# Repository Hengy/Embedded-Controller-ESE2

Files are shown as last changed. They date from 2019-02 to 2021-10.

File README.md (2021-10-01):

# Embedded-Controller-ESE2

This repository contains project files for the 2nd year Conestoga ESE project: Embedded Robot Controller PCB.

The PCB is a 4-layer board with connections for a STM32F303 Nucleo development board, LCD display, RS232 port, uSD card slot, RTC backup battery, Stepper motor driver, Dual DC motor driver, CANbus transciever, Bluetooth module, ultrasonic distance sensor, encoder input, and GPIO. GPIO include I2C and SPI connections.

The board runs of 12-14V, and includes a 5V switch mode buck converter, and a 3V3 linear regulator. Voltage input includes reverse polarity protection.

Layer stackup: (1) signal with ground plane (2) 5V power (3) ground (4) signal with ground plane.

PCB features include thermally enhanced features for motor drivers, thermistors for motor drivers to monitor temperature, numerous and easily accessilble test points, mechanical support for LCD display module, GPIO headers compatible with Tektronics MSO digital probes, and 5V and 3V3 isolation for debugging.

Switch mode power supply adheres to SMPS layout best practices, including small loop area.

Majority of components are SMD. PCB is capable of being oven reflowed on both sides - bottom first. Hand soldering is possible.

Project includes full 3D model.

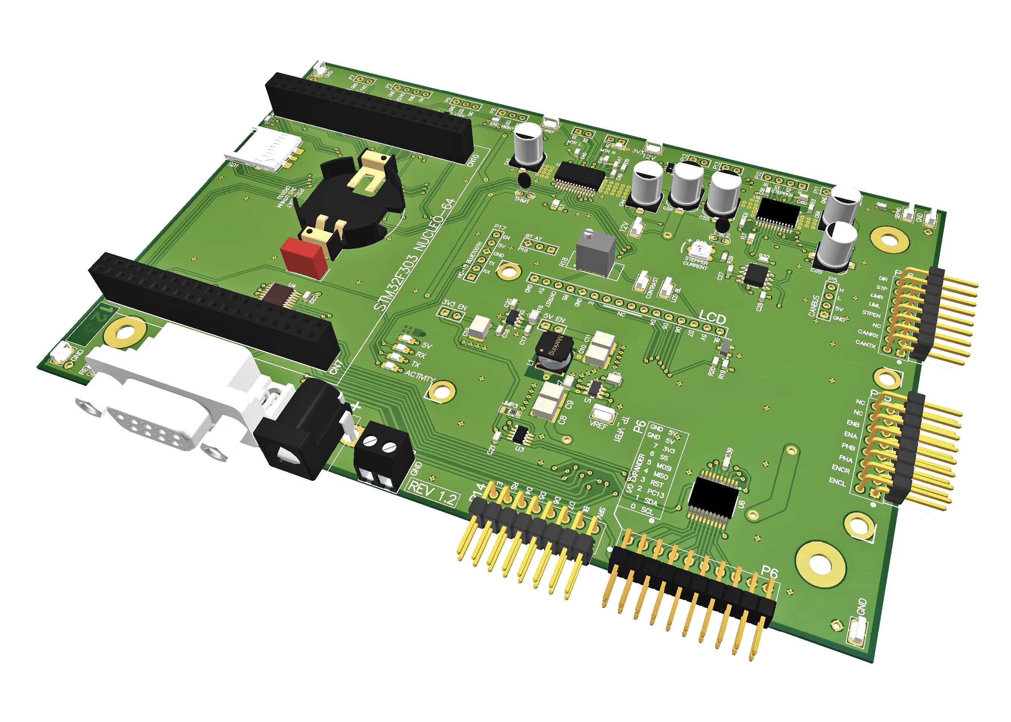
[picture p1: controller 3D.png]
PCB


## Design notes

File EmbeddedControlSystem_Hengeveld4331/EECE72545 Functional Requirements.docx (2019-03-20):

EECE72545

Project Functional Requirements

Matthew Hengeveld

8534331

2/27/2019

Document Title | Hardware Functional Specification
Revision | 1.2
Date Issued | March 4, 2019
Date Effective | March 4, 2019
Program | Electronic Systems Engineering
Author | Matthew Hengeveld
Reviewers | Matthew Hengeveld

REVISION HISTORY

Revision | Description of Change | Effective Date
1.0 | Initial Release | Jan 18, 2019
1.1 | Updated Topics | Feb 15, 2019
1.2 | PCB Layout Completion Update | Mar 8, 2019

TABLE OF CONTENTS

Document Scope | 3
Cost Targets | 3
Configuration Options | 3
Hardware Description | 4
STM32F303RE Nucleo | 4
Pin Table | 5
Serial | 8
CANbus | 9
DC Motor Driver | 10
Inverting Schmitt Trigger | 11
Camera Module | 13
Servo | 13
Stepper Motor Driver | 14
LCD | 17
IO Expander | 18
Temperature Sensors | 19
Power | 20
Power Budget | 20
5V Switching Regulator | 21
3V3 Linear Regulator | 25
Power Monitor | 27
Extras | 28
Ultrasonic Sensors | 28
Bluetooth | 28
LED Indicators | 28
Environmental Requirements | 29

Document Scope

This project will consist of designing and building a controller board for a robot, to interface and control various actuators on the robot platform. The project will take about eight weeks, with 6 weeks devoted to designing schematics, and 2 weeks on PCB layout. The result will be a PCB with all components soldered, and ready to start programming.

This document outlines all the requirements for each component on the controller board, as well as the component chosen, the pins used to interface, any configuration options, and any necessary calculations for power, temperature, current, etc.

Cost Targets

The target cost for manufacturing of the PCB, parts, and soldering is $200CDN max. The cost of one PCB is $66USD.

Configuration Options

The controller board should include as many configurable options as possible to aid in debugging.

Hardware Description

STM32F303RE Nucleo

The STM32F303RE Nucleo Development board includes the main processor for the controller board. It includes a programming interface, local power regulation, and breakouts for many of its pins. These pins interface with the rest of the Embedded Controller Board, and the pins include:

- Serial
- CANbus
- SPI
- I2C
- Timers
- ADC
- Power

Pin Table

The following described each pin of the STM32F303, and its function on the embedded controller board.

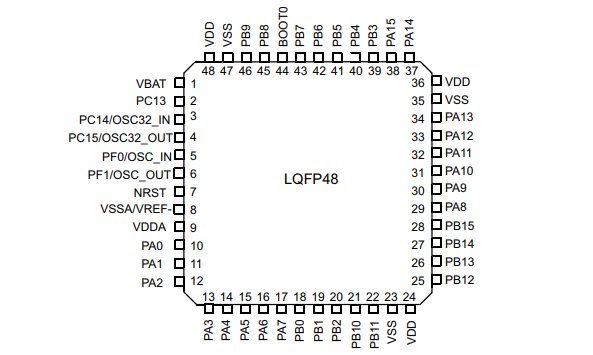
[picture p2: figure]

Pin | Function | Alternate Function | Description
PA0 | CTS | USART2_CTS | Serial CTS (Clear to Send)
PA1 | RTS | USART2_RTS | Serial RTS (Request to Send)
PA2 | TX | USART2_TX | Serial TX (Transmit)
PA3 | RX | USART2_RX | Serial RX (Receive)
PA4 | LCD_RS | | LCD RS signal
PA5 | IO1 | | GPIO
PA6 | TEMP1 | | NTC temperature sensor for DRV8814 DC motor driver
PA7 | TEMP2 | | NTC temperature sensor for DRV8884 stepper motor driver
PA8 | ENCL | TIM1_CH1 | Left DC motor encoder
PA9 | ENCR | TIM1_CH2 | Right DC motor encoder
PA10 | STP_FLT | | DRV8884 fault output. Active-low LED
PA11 | CAN_RX | CAN_RX | CANbus RX (Receive)
PA12 | CAN_TX | CAN_TX | CANbus TX (Transmit)
PA15 | SERVO | TIM2_CH1 or TIM8_CH1 | Servo motor signal
PB0 | LCD_E | | LCD E signal
PB1 | LIML | | Left stepper motor limit switch
PB2 | LIMR | | Right stepper motor limit switch
PB3 | STP_EN | | DRV8884 enable
PB4 | STP_DIR | | DRV8884 direction
PB5 | STP_STEP | TIM3_CH2 or TIM17_CH1 | DRV8884 step
PB6 | SPI_SS_SD | | SD card SPI slave select⁽²⁾
PB7 | BL_PWM | TIM4_CH2 or TIM3_CH4 | LCD backlight PWM signal
PB8 | I2C_SCL | I2C1_SCL | I²C Serial Clock
PB9 | I2C_SDA | I2C1_SDA | I²C Serial Data
PB10 | IO_INT | | MCP23S08 interrupt signal
PB11 | CAN_STBY | | MCP2542 standby
PB12 | SPI_SS | SPI2_NSS⁽¹⁾ | SPI slave select
PB13 | SPI_SCK | SPI2_SCK | SPI Serial Clock
PB14 | SPI_MISO | SPI2_MISO | SPI Master In Slave Out
PB15 | SPI_MOSI | SPI2_MOSI | SPI Master Out Slave In
PC0 | LCD_DATA1 | | LCD Data bit 1
PC1 | LCD_DATA2 | | LCD Data bit 2
PC2 | LCD_DATA3 | | LCD Data bit 3
PC3 | LCD_DATA4 | | LCD Data bit 4
PC4 | STP_SLP | | DRV8884 sleep
PC5 | DC_PHASEA | | DRV8814 Phase A
PC6 | DC_PHASEB | | DRV8814 Phase B
PC7 | ULTRA_SIG | TIM3_CH2 or TIM8_CH2 | Ultrasonic output signal
PC8 | DC_ENA | TIM3_CH3 or TIM8_CH3 | DRV8814 enable A
PC9 | DC_ENB | TIM3_CH4 or TIM8_CH4 | DRV8814 enable B
PC10 | DC_RST | | DRV8814 reset
PC11 | DC_SLP | | DRV8814 sleep
PC12 | DC_FLT | | DRV8814 fault output. Active-low LED
PC13 | RTC | RTC_OUT | Real-Time Cock output
PC14 | ULTRA_TRIG | | Ultrasonic trigger signal
PD2 | HEARTBEAT | | Heartbeat LED
RESET | RESET | | STM32F303 & MCP23S08 reset signal. Active low
VBAT | | | RTC battery
AGND | | | Analog ground
GND | | | Ground

(1) SPI slave select can also be a GPIO pin. It is required to be a GPIO is there are more than one devices on the bus.
(2) Not connected to hardware SPI module. Slave select signal must be formed with GPIO

Serial

Serial communications will be used to control and receive messages from the Embedded Control Board. It will also aid in debugging. The serial communications will use 3V3 logic levels from the STM32 to a RS232 transceiver. The requirements for the serial transceiver are:

- 3-5V Supply Voltage
- Minimum 100Kbps data rate
- Minimum of 2 TX/RX pins (one of each); recommended 4 (two of each)
- Accepts ±25V RS232-levels
- Small package, SMD, ceramic charge-pump capacitors
- Leaded SMD package

Utilized device: ICL3232

The ICL3232 is a low power, 3-5.5V, RS232 transceiver with dual-transmitters and dual-receivers. The ICL3232 uses charge-pumps for RS232 voltage level generation, compatible with 0.1µF capacitors for PCB space reduction.

Critical specifications include:

Specification | Value | Condition
VCC | 3.3V
Input Logic Threshold High | 2V min. | VCC = 3.3V
Transmitter Output Voltage | ±5V min.
Transmitter Output Short Circuit Current | ±60mA max.
IC Package | 16 TSSOP
Number of Supporting Components | 9 approx.

The ICL2323 does not have significant thermal dissipation.

There are no hardware configuration options for serial.

Pin configuration:

- PA2 – This is the TX pin. It has an active-low LED
- PA3 – This is the RX pin. It has an active-low LED
- PA0 – This is the CTS pin
- PA1 – This is the RTS pin

There are 2 external connections for the serial module.

- DB9 connector – This connection is a standard Serial DB9 connector with TX, RX, CTS, DTS and GND
- Header – This connection is a 6-pin, 2.54mm header with TX and RX connections. This header is intended to interface with a HC-10 Bluetooth module.

CANbus

The Embedded Control Board will eventually connect to a CANbus network. A CANbus transceiver will interface to the integrated CAN controller in the STM32 via 3.3V logic levels. The requirements for the CANbus transceiver are:

- Compatible with 3.3V logic levels
- Integrated ESD and fault protection
- Low current standby
- High-speed CAN capable
- Leaded SMD package

Utilized device: MCP2542

The MCP2542 is a high-speed CANbus transceiver. The MCP2542 supports multiple CAN data rate standards (2.0 and FD), has separate logic and CANbus voltage supplies, and has several CANbus and self-protection features. Protections include ground fault, thermal, voltage transient, and unpowered bus disconnect protection, as well as meeting automotive EMC requirements.

Critical specifications include:

Specification | Value | Condition
VDD | 5V
VIO | 3.3V
Maximum Supply Current | 140mA max. | Fault Condition
Transmitter Output Short Circuit Current | ±115mA max.
IC Package | 8 SOIC
Number of Supporting Components | 9 approx.

The MCP2542 does not have significant thermal dissipation when VDD = 5V.

There are no hardware configuration options for CANbus.

Pin configuration:

- PA12 – This is the CANbus TX pin
- PA11 – This is the CANbus RX pin
- PB11 – This pin controls the MCP2542 standby (ON/OFF)

There are 1 external connection1 for the CANbus module.

- There is one, 4-pin 2.54mm headers for CANbus TX, CANbus Rx, 5V and GND

DC Motor

The Embedded Control Board will control two brushed DC motors, each with a IR LED-based encoder. The DC motor driver must be able to drive both DC motors, independently, in both directions. Protection systems are a requirement. The motor driver must operate at the maximum battery voltage. Low RDS(ON) for cooler operation is a desirable feature. The requirements for the DC motor driver are:

- Compatible with 3.3V logic levels
- Integrated over-current, thermal and fault protection
- Low current standby
- 14.8V supply voltage capable
- RDS(ON) <=500mΩ
- Leaded, thermally enhanced SMD package

Utilized device: DRV8814

The DRV8814 dual H-bridge DC motor driver, with a phase/enable interface, programmable decay and current control, sleep mode, and 1.75A RMS output current per H-bridge. The DRV8814 includes over-current protection, thermal protection, and an open-drain fault output. The operating voltage of the DRV8814 is 8-45V.

Critical specifications include:

Specification | Value | Condition
VVM | 14.8V max.
Continuous Output Motor Current | 2.5A peak/1.75A RMS | 25°C
Logic Level Input High | 2V min
RDS(ON) HIGH/LOW | 0.25Ω/0.25Ω max. | 25°C
Operating Junction Temperature | 150°C max.
IC Package | 28 HTSSOP w/ PowerPad
Number of Supporting Components | 19 approx.

Worse case power dissipation (VM = 14.8V, IOUT = 1.5A, 25°C):

P_(RDS(ON)) =(2)(R_(DS(ON)HS+LS) )(I_(OUT) ^2 )=(2)(0.525Ω)(1.5A^2 )=2.36W

P_(SW) =(V_M )(I_(OUT) )(t_(F,R) )(f_(SW) )=(14.8V)(1.5A)(300ns)(50KHz)=0.333W

P_(IVM) =(V_M )(I_(IVM) )=(14.8V)(5mA)=0.074W

P_(LDO) =(V_M -V_(LDO) )(I_(LDO OUT) )=(14.4V-3.3V)(1mA)=0.0115W

P_(TOTAL) =P_(RDS(ON)+) P_(SW) +P_(IVM) +P_(LDO) =2.775W

Worse case IC temperature:

T_J =T_A +(P_(TOTAL) )(R_(θJA) )=25°C+(2.775W)(31.6(°C)/W)=112.7°C

112.7°C is well below the max operating junction temperature for the DRV8814 of 150°C.

Hardware configurations:

- AI1 – This jumper sets one of two current limit bits for H-bridge A of the DRV8814
- AI2 – This jumper sets two of two current limit bits for H-bridge A of the DRV8814
- BI1 – This jumper sets one of two current limit bits for H-bridge B of the DRV8814
- BI2 – This jumper sets two of two current limit bits for H-bridge B of the DRV8814

Pin configurations:

- PC8 – This is the Enable input pin for H-bridge A. It will be configured as a PWM on TIMx, and activates or deactivates the DC motor
- PC5 – This is the Phase input pin for H-bridge A. It controls the direction of the DC motor
- PC9 – This is the Enable input pin for H-bridge B. It will be configured as a PWM on TIMx, and activates or deactivates the DC motor
- PC6 – This is the Phase input pin for H-bridge B. It controls the direction of the DC motor
- PC10 – This is the Reset input pin for the DRV8814
- PC11 – This is the Sleep input pin for the DRV8814
- PC12 – This is the Fault output pin of the DRV8814. This pin has an active-low LED

There are 2 external connections for the DC motor.

- There are two, 2-pin 2.54mm headers. Each for a DC motor
- There is a test pin on the VREF pin

The motor encoders use LED interruption to create a signal proportional to the speed of the DC motors. The maximum frequency of the signal will be approx. 2Khz. A low-pass RC filter will filter out higher-frequency noise, and an inverting Schmitt trigger will provide signal conditioning and additional noise filtering.

Utilized device: 74LVC2G14

The 74LVC2G14 is a dual-inverting Schmitt trigger, compatible with 3V and 5V logic devices.

Critical specifications include:

Specification | Value | Condition
VCC | 14.8V max.
Logic Level Input Low | 0.55V max. | VCC = 3V
Logic Level Input High | 2.3V min. | VCC = 3V
Hysteresis | 0.73V typ. | VCC = 3V
Total Power Dissipation | 250mW max.
IC Package | SOT-363

The 74LVC2G14 does not have significant thermal dissipation.

There are no hardware configurations for the 74LVC2G14.

Pin configurations:

- PA8 – This is the left encoder signal. It is an input to the STM32F303
- PA9 – This is the right encoder signal. It is an input to the STM32F303

There are 2 external connections for the serial module.

- There are two, 3-pin 2.54mm headers. Each has an encoder signal, 3V3 with current limiting resistor, and a GND pin

Camera Module

The camera module includes the servo motor, stepper motor, and limit switches.

Servo

The servo motor needs a PWM signal for operation. The STM32F303 can provide this signal without any external ICs and minimal components.

Pin configuration:

- PA15 – This is the signal for the servo motor. It will be configured as a PWM on TIMx

There are 2 external connections for the servo motor.

- There is one, 3-pin 2.54mm headers. The header has 5V, signal and GND
- There is a test pin on the signal pin

Stepper Motor

The Embedded Control Board will control a stepper motor, with two limit switches to indicate the rotational limits in both directions. The stepper driver must be able to drive a unipolar motor. Protection systems are a requirement. The stepper driver must operate at the maximum battery voltage. Low RDS(ON) for lower temperature operation is a desirable feature. The requirements for the stepper motor driver are:

- Compatible with 3.3V logic levels
- Step/direction controls • Integrated over-current, thermal and fault protection
- Low current standby
- 14.8V supply voltage capable • RDS(ON) <=1Ω
- Mixed decay mode
- Leaded, thermally enhanced SMD package

Utilized device: DRV8884

The DRV8884 is a quad half H-bridge stepper motor driver, with step/direction control, with programmable microstepping, programmable decay, sleep mode, and 700mA RMS output current per bridge. The DRV8884s step/direction has an integrated step pattern. The DRV8814 includes over-current protection, thermal protection, and an open-drain fault output. The operating voltage of the DRV8814 is 8-37V.

Critical specifications include:

Specification | Value | Condition
VVM | 14.8V max.
Continuous Output Motor Current | 1A peak/700mA RMS | 25°C
Logic Level Input High | 1.6V min
RDS(ON) HIGH/LOW | 0.798Ω/0.749Ω max. | 25°C
Operating Junction Temperature | 150°C max.
IC Package | 24 HTSSOP w/ PowerPad
Number of Supporting Components | 14 approx.

Worse case power dissipation (VM = 14.8V, IOUT = 0.4A, 25°C):

P_(RDS(ON)) =(R_(DS(ON)HS) )(I_(OUT) ^2 )+(R_(DS(ON)LS) )(I_(OUT) ^2 )

=(0.798Ω)(0.4A^2 )+(0.749Ω)(0.4A^2 )=0.247W

P_(SW) =(V_M )(I_(OUT) )(t_(F,R) )(f_(SW) )=(14.8V)(0.4A)(100ns)(50KHz)=0.029W

P_(IVM) =(V_M )(I_(IVM) )=(14.8V)(5mA)=0.074W

P_(TOTAL) =P_(RDS(ON)) +P_(SW) +P_(IVM) =0.35W

Worse case IC temperature:

T_J =T_A +(P_(TOTAL) )(R_(θJA) )=25°C+(0.35W)(31.6(°C)/W)=36.0°C

36.0°C is well below the max operating junction temperature for the DRV8884 of 150°C.

Hardware configurations:

- M1, M2 – These jumpers set the microstepping setting for the DRV8884

Pin configurations:

- PB3 – This is the Enable input pin. It activates or deactivates the stepper motor
- PB5 – This is the Step input pin. It steps the stepper motor. It will be configured as a PWM on TIMx
- PB4 – This is the DIR input pin. It controls the direction of the stepper motor
- PC4 – This is the Sleep input pin for the DRV8884
- PA10 – This is the Fault output pin of the DRV8884. This pin has an active-low LED

There are 2 external connections for the serial module.

- There is one, 4-pin 2.54mm header
- There is a test pin on the VREF pin

The limit switches activate when the camera module reaches either the left or right rotational limits. Limit switches exhibit switch bounce on activation A low-pass RC filter, and an inverting Schmitt trigger will provide switch debouncing.

Utilized device: 74LVC2G14

For a description of the 74LVC2G14, see the DC Motor section of this document.

There are no hardware configurations for the 74LVC2G14.

Pin configurations:

- PB1 – This is the left limit switch. It is an input to the STM32F303
- PB2 – This is the right limit switch. It is an input to the STM32F303

There is 1 external connection for the stepper motor.

- There are two, 2-pin 2.54mm headers. Each has a signal, and a GND pin

LCD

The LCD module will display information in text form. It must be powered by 3.3V or 5V, and use a low pin-count interface. A backlight would be beneficial. The requirements for the LCD are:

- HD44780 compatible interface
- Compatible with 3.3V logic levels
- Low pin-count interface
- Through-hole, 0.1” pin header connection

Utilized device: 0216K1Z by Newhaven Display

The 0216K1Z is a low power, 16x2, FSTN negative, LED backlight LCD module. It is HD44780 compatible, and will be used in 4-bit parallel, write only mode. The LCD has contrast control, and a blue LED backlight, with PWM dimmable interface.

Critical specifications include:

Specification | Value | Condition
VDD | 5V
Logic Level Input High | 0.7VDD min.
LED Backlight Voltage | 5V typ.
LED Backlight Current | 8mA typ.
Number of Supporting Components | 7 approx.

The 0216K1Z does not have significant thermal dissipation.

Hardware configurations:

- R16 – This potentiometer sets the contrast for the LCD

Pin configurations:

- PA4 – This is the RS input pin for the LCD
- PB0 – This is the E input pin for the LCD
- PC0, PC1, PC2, PC3 – These are the data pins for the 4-bit interface of the LCD
- PB7 – This is the backlight PWM signal for the LCD. It is connected to the gate of a N-MOSFET to increase the current available.

There are 3 external connections for the LCD module.

- There is one, 16-pin 2.54mm header
- There is a test pin on the LCD contrast pin
- There is a test pin on the Backlight PWM pin

IO Expander

An IO expander will provide 8 additional digital GPIO, as the STM32F303RE does not have many free IO pins left. The IO expander should utilize a bus – either SPI or I²C. The requirements for the IO expander are:

- Utilizes SPI or I²C bus
- Compatible with 3.3V logic levels
- Leaded, thermally enhanced SMD package

Utilized device: MCP23S08

The MCP23S08 is an 8 port, SPI interface IO expander. It also has two address pins, and an interrupt pin that triggers on pin change.

Critical specifications include:

Specification | Value | Condition
VDD | 3.3V
Max SPI Clock | 10MHz
VDD Current | 125mA max.
Pin Current | 25mA max.
Number of Supporting Components | 5 approx.

The MCP23S08 does not have significant thermal dissipation.

There are no hardware configurations for the MCP23S08.

Pin configurations:

- PB12 – This is the Slave Select input pin for the MCP23S08
- PB13 – This is the Serial Clock input pin for the MCP23S08
- PB14 – This is the Master In, Slave Out pin for the MCP23S08
- PB15 – This is the Master Out, Slave In pin for the MCP23S08
- RESET – This is the Reset pin for the MCP23S08. It is directly connected to the Reset pin on the STM32F303
- PB10 – This is the IO Interrupt pin output for the MCP23S08

There are 3 external connections for the MCP23S08:

- There is 1, 20-pin, dual row, 2.54mm header. It has 8 pins for the MCP23S08 GPIO, and also breaks out SPI, RESET, RTC (PC13), I²C, 5V, 3V3, and GND
- There is 1, 2-pin 2,54mm header for an additional GPIO from the STM32F303 (PA5)
- There is a test pin on the Reset pin

Temperature Sensors

Each motor driver has a NTC thermistor for it. While both motor drivers have thermal protection, there are also benefits to knowing and monitoring the temperature of the motor drivers. Prolonged high temperatures can have long-term, detrimental effects on ICs. Knowing the temperature, and the slope of temperature change can help predict and diagnose problems. The expected temperatures are from 10°C - 150°C. A lower resistance tolerance (<= 1%) is preferred.

Critical specifications include:

Specification | Value | Condition
Resistance | 10KΩ | 25°C
Temperature Range | -40°C to 180°C
B25/85 | 3500K typ.

POWER

There are several external components at the input of the battery voltage. These components protect the circuitry on the PCB. These components are:

- Reverse protection diode – This is a low Vf Schottky diode that protects against VBAT and GND being accidentally swapped at the input terminals.
- There are two input terminals: a 2.1mm(ID) x 5.5mm(OD) barrel jack, and a 2-pin, 3.5mm screw terminal. Both can be used for VBAT, and the unused can be used as an auxiliary VBAT output
- There are two ceramic capacitors as close to the input terminals as possible for input noise reduction.

Critical specifications for the Schottky diode include:

Specification | Value | Condition
Vf | 500mV | @ 8A
VDC REVERSE | 40V
IAVERAGE RECTIFIED | 8A max.
IC Package | DO-214AB, SMC

Power Budget

The Embedded Controller Board will use two power supply voltages, in addition to the battery voltage. The 3V3 power rail will be supplied by the 5V rail. The linear conversion from 5V to 3V3 is assumed to be 50% efficient. The following is the power budget (worse case) for the 5V and 3.3V rails, with 20% extra calculated:

Rail | Budget (+20%) | Power
3V3 | 32mA | 106mW
5V | 557mA | 2.919W
Total | | 3.025W

5V Switching Power Supply

The 5V power supply will power many parts of the Embedded Controller, as well as the servo motor. A switching power supply will provide efficient power conversion. The requirements for the 5V switching power supply are:

- 5V output voltage
- Greater than 14.8V maximum input voltage
- Minimum 700mA output current
- Better than 85% efficiency at >100mA output current
- Compatibility with low-ESR ceramic output capacitors
- Small, leaded SMD package

Utilized part: TPS562201

The TPS562201 is a 2A, synchronous buck converter. The TPS562201 provides fast transient response, has internal compensation, is compatible with low-ESR output capacitors, and has high efficiency at small loads. The TPS562201 also has soft-start, output over-current protection, under-voltage lockout, and thermal shutdown protection. The TPS562201 has an input voltage of 4.5-17V. The 580KHz operating frequency of the TPS562201 is sufficiently far from the 50KHz internal PWM frequency of the motor drivers.

Hardware configuration:

- There is a single jumper on the output of the TPS562201 that disconnects it from the rest of the board

Pin configuration:

- The output of the TPS562201 is connected to an inductor, which is connected to an active-high LED

There are no external connectors for the TPS562201.

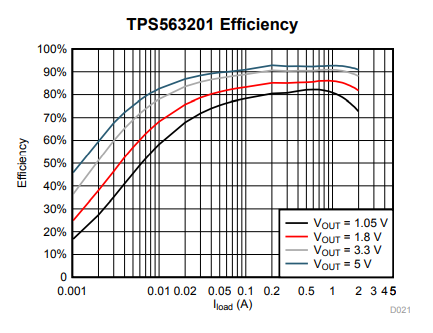
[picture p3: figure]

Figure 1: TPS562201 efficiency. 5V output voltage

Critical specifications include:

Specification | Value | Condition
VINPUT | 4.5-17V
VOUTPUT | 0.76-7V
Internal Current Limit | 4A max.
Switching Frequency | 580KHz | L1 = 2.2µH
RDS(ON) HIGH/LOW | 0.14Ω/0.084Ω typ. | 25°C
IC Package | 6-SOT-23 THIN
Number of Supporting Components | 11 approx.

The design parameters for the 5V switching power supply are:

Parameter | Value
Input Voltage | 12-14.8V
Output Voltage | 5V
Output Current | 1A

Worse case power dissipation (IOUT = 1A, 25°C):

The following method was taken from TI: Application Report AN-1566 “Techniques for Thermal Analysis of Switching Power Supply Designs”

P_(BIAS) =I_q ×V_(IN) =750µA×14.8V=0.011W

P_(COND) =Duty×[(R_(DS(ON)HS) ×I_(OUT) ^2 )+(R_(DS(ON)LS) ×I_(OUT) ^2 )]=35%×[(0.14Ω×1A^2 )+(0.084Ω×1A^2 )]

=0.078W

P_(SW) =((I_(OUT) ×V_(IN) ))/2×f_(SW) ×(t_R +t_F )

=((1A×14.8V))/2×580KHz×(50ns)=0.215W

P_(TOTAL) =P_(BIAS) +P_(COND) +P_(SW) =0.31W

Worse case IC temperature:

T_J =T_A +(P_(TOTAL) )(R_(θJA) )=25°C+(0.31W)(90.8(°C)/W)=53.1°C

53.1°C is well below the max operating junction temperature for the TPS562201 of 125°C. Using the TI WEBENCH online tool, the power dissipation of the TPS562201, using the same conditions, was calculated to be 0.35W, with a junction temperature of 46°C, however, it uses a ϴJA=60°C/W. This value is different than the value in the datasheet, which was used in the above calculation.

Component selection calculations:

Output Voltage Resistors:

V_(OUT) =0.768×(1+(R5)/(R6))

Choosing R6 = 10K, gives

R5=((10000V_(OUT))/0.768)-10000=56KΩ

The inductor value and output capacitor(s) value(s) were chosen from Table 2 of the TPS562201 datasheet.

The inductor peak-to-peak current is:

I_(P-P) =(V_(OUT))/(V_(IN(MAX)))×((V_(IN(MAX)) -V_(OUT) ))/(L_O ×f_(SW))

=(5V)/(14.8V)×((14.8V-5V))/(4.7μH×580KHz)=1.21A

The inductor peak current is:

I_(PEAK) =I_O +(I_(P-P))/2=1A+(1.21A)/2=1.60A

The RMS inductor current is:

I_(RMS) =√(I_O ^2 +1/12I_(P-P) ^2)=1.12A

Utilized part: 74404064047

Using TI WEBENCH, the following parameters were calculated:

Parameter | Value (Ideal)
Duty Cycle | 35.02%
Efficiency | 93.1%
VOUT P-P | 7.72mV

3V3 Linear Power Supply

The 3V3 power supply will power several lower power parts of the Embedded Controller. While the Nucleo has its own 3V3 regulator, an external regulator will have greater current capacity for external devices. It could also have better regulation and noise characteristics, and thermal regulation. Powering devices from 3V3 can simplify interfacing between devices, as no level converters are needed. The requirements for the 3V3 power supply are:

- 3V3 output voltage
- 5V input voltage
- Minimum 100mA
- Small, leaded SMD package with good thermal dissipation

Utilized part: CAT6219

The CAT6219 is a 500mA low-dropout linear regulator. The CAT6219 is compatible with low-ESR output capacitors and has a 300mV dropout voltage. The CAT6219 also has a quick-start feature, under-voltage lockout, current limit, and thermal protection.

Critical specifications include:

Specification | Value | Condition
VINPUT | 2.3-5.5V
VOUTPUT | 3V3
Internal Current Limit | 500mA max.
PSRR | >54dB | 10nF bypass cap
IC Package | TSOT-23
Number of Supporting Components | 7 approx.

Power dissipation:

P_D =(V_(IN) -V_(OUT) )×I_(OUT) =(5.0-3.3)×32mA=4.89mW

Worse case IC temperature:

T_J =T_A +(P_(TOTAL) )(R_(θJA) )=25°C+(0.00489W)(235(°C)/W)=26.15°C

Hardware configuration:

- There is a single jumper on the output of the CAT6219 that disconnects it from the rest of the board

Pin configuration:

- The output of the CAT6219is connected to an inductor, which is connected to an active-high LED

There are no external connectors for the CAT6219.

Power Monitor

In order to monitor voltage and current from the batteries, a power monitor IC will be used. The power monitor should be accurate at low current and should use low value current sense resistors to minimize power consumption. The power monitor should use the SPI or I²C bus. The requirements for the 3V3 power supply are:

- Minimum 14.8V input voltage
- Minimum 4A current sensing
- Small, leaded SMD package

Utilized part: INA219

The INA219 is an I2C current and power monitor. The INA219 has programmable averaging, gain amplifiers, and calibration registers. The INA219 uses the voltage drop across a low-value current sense resistor, along with the sensed voltage to monitor voltage, current and power. For increase thermal dissipation, two resistors are used in parallel. There is a low-pass filter on each input, consisting of a 10R series resistor and a 100nF capacitor.

Critical specifications include:

Specification | Value | Condition
VSENSE | 0-26V
VSUPPLY | 3-5V
Current Sense Error | <2.0% @ >100mA >0.6% @ >1A | 25°C, 0.025Ω Sense Resistor
IC Package | SOT-23-8
Number of Supporting Components | 6 approx.

The INA219 does not have significant thermal dissipation.

Error values calculated using TI website INA219 Error Analysis Tool.

Hardware configuration:

- JMP3 – This jumper sets the address bit A1. It connects to either 3V3 or GND

Pin configurations:

- PB8 – This is I²C Serial Clock input to the INA219. It has a 3K3 pullup resistor
- PB9 – This is I²C Serial Data input to the INA219. It has a 3K3 pullup resistor

Extras

There are several “extras” implemented on the embedded controller board. There are also GPIO, SPI, and I²C pins on headers for interfacing with other external modules.

Ultrasonic Sensor

There is a header for a HC-SR04 ultrasonic sensor.

Bluetooth Module

There is a header for a HC-5/6/10 Bluetooth module. This will be capable of sending and receiving serial over Bluetooth.

LED Indicators

Many circuits on the embedded controller board have LEDs to show status, data, or other necessary information. A table of LEDs, their description, and their associated current-limiting resistor value is shown:

LED | Description | Resistor Value
5V Power | Green. Indicates 5V power is on. | 470Ω
Heartbeat | Blue. Indicates STM32F303 is running main loop. | 470Ω
TX | Green. Indicates Serial TX activity. | 1.2KΩ
RX | Red. Indicates Serial RX activity. | 680Ω
DC Fault | Red. Indicates DC motor driver in fault state. | 1KΩ
Stepper Fault | Red. Indicates DC motor driver in fault state. | 1KΩ

Configuration Jumpers

Configuration jumpers on the embedded controller board set many functions. A table of jumpers, their description, and their associated default setting is shown:

Jumper(s) | Description | Default Indicator
AI0, AI1 | Selects current limit for DC H-Bridge A. 11 = disabled, 10 = 38%, 01 = 71%, 00 = 100% | 00
BI0, BI1 | Selects current limit for DC H-Bridge B. 11 = disabled, 10 = 38%, 01 = 71%, 00 = 100% | 00
M1, M2 | Selects microstepping setting for stepper motor. 00 = Full Step, 01 = 1/16 Step, 10 = ½ Step, 11 = ¼ Step | 00
5V | Enables 5V power. | -
3V3 | Enables 3V3 power. | -
JMP3 | Selects bit 1 of INA219 address. | 0

Environmental Requirements

The embedded controller board must be able to work reliably in temperatures from 10°C to 40°C.

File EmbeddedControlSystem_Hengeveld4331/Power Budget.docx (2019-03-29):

EECE72545

Power Budget

Matthew Hengeveld

8534331

3/21/2019

Device Power Consumption:

Component/Device | Number of units | Worst case | Standby | Nominal Voltage | Total power | Note
TPS562201 | 1 | 750 µA | 1 µA | 14.8V | 11 mW | [1]
Power LED | 1 | 0.73 mA | 0.73 mA | 3V3 | 2.4 mW
CAT6219 | 1 | 90 µA | 1 µA | 5V | 0.45 mW | Quiescent
INA219 | 1 | 1 mA | 6 µA | 3V3 | 3.3 mW
‘Heartbeat’ LED | 1 | 0.07 mA | 0 | 3V3 | 231 mW
ICL3232 | 1 | 121 mA | 1 µA | 3V3 | 399 mW
TX/RX LED | 2 | 2.86 mA | 0 | 3V3 | 9.5 mW
MCP2542 | 1 | 140 mA | 4 µA | 3V3 | 100 mW
LCD | 1 | 3 mA | 1 mA | 5V | 15 mW
LCD Backlight | 1 | 20 mA | 0 | 5V | 100 mW
MCP23S08 | 1 | 125 mA | 1 µA | 3V3 | 412.5 mW
DRV8814 | 1 | | | | | [²]
Stepper Motor | 1 | 400 mA | 0 | 14.8V | 5.92 W | Half-stepping
DRV8884 | 1 | | | | | [³]
DC Motor | 2 | 3 A | 0 | 14.8V | 44.4 W | Stall
Fault LED | 2 | 20 mA | 0 | 3V3 | 66 mW
74LVC2G14 | 1 | 200 mA | 8 µA | 3V3 | 660 mW | Outputs shorted
Servo | 1 | 300 mA | 0 | 5V | 1.5W
HC-10 Bluetooth | 1 | 50 mA | 200 µA | 3V3 | 165 mW | Transmit mode
µSD Card | 1 | 50 mA | - | 3V3 | 165 mW | Writing
NTC Thermistor | 2 | 2.2 mA | 2.2 mA | 3V3 | 7.3 mW
Ultrasonic Rangefinder | 1 | 20 mA | 2.5mA | 5V | 100 mW | Transmitting

[1] TPS562201 Power Consumption:

Worse case power dissipation (IOUT = 1A, 25°C):

The following method was taken from TI: Application Report AN-1566 “Techniques for Thermal Analysis of Switching Power Supply Designs”

P_(BIAS) =I_q ×V_(IN) =750µA×14.8V=0.011W

P_(COND) =Duty×[(R_(DS(ON)HS) ×I_(OUT) ^2 )+(R_(DS(ON)LS) ×I_(OUT) ^2 )]=35%×[(0.14Ω×1A^2 )+(0.084Ω×1A^2 )]

=0.078W

P_(SW) =((I_(OUT) ×V_(IN) ))/2×f_(SW) ×(t_R +t_F )

=((1A×14.8V))/2×580KHz×(50ns)=0.215W

P_(TOTAL) =P_(BIAS) +P_(COND) +P_(SW) =0.31W

[2] DRV8814 Power Consumption:

The DRV8814 has internal 5V and 3V3 regulators.

Worse case power dissipation (VM = 14.8V, IOUT = 1.5A, 25°C):

P_(RDS(ON)) =(2)(R_(DS(ON)HS+LS) )(I_(OUT) ^2 )=(2)(0.525Ω)(1.5A^2 )=2.36W

P_(SW) =(V_M )(I_(OUT) )(t_(F,R) )(f_(SW) )=(14.8V)(1.5A)(300ns)(50KHz)=0.333W

P_(IVM) =(V_M )(I_(IVM) )=(14.8V)(5mA)=0.074W

P_(LDO) =(V_M -V_(LDO) )(I_(LDO OUT) )=(14.4V-3.3V)(1mA)=0.0115W

P_(TOTAL) =P_(RDS(ON)+) P_(SW) +P_(IVM) +P_(LDO) =2.775W

[3] DRV8884 Power Consumption:

The DRV8884 has internal 5V and 3V3 regulators.

Worse case power dissipation (VM = 14.8V, IOUT = 0.4A, 25°C):

P_(RDS(ON)) =(R_(DS(ON)HS) )(I_(OUT) ^2 )+(R_(DS(ON)LS) )(I_(OUT) ^2 )

=(0.798Ω)(0.4A^2 )+(0.749Ω)(0.4A^2 )=0.247W

P_(SW) =(V_M )(I_(OUT) )(t_(F,R) )(f_(SW) )=(14.8V)(0.4A)(100ns)(50KHz)=0.029W

P_(IVM) =(V_M )(I_(IVM) )=(14.8V)(5mA)=0.074W

P_(TOTAL) =P_(RDS(ON)) +P_(SW) +P_(IVM) =0.35W

Per Rail Power Consumption:

Rail | Total Power
5V | 1715.45 mW
3V3 | 2311 mW

Efficiency Corrected Power Consumption:

Because the 5V and 3V3 rails are converted from the battery voltage, there are losses associated with each conversion. The efficiency of the TPS562201 is about 91% at 300mA, and the CAT6219, being a linear regulator, is about 50%. Therefore, 3V3 rail could draw a total 2.888W from the 5V rail. The 5V rail, along with the previously calculated 3V3 draw, could draw a total 5.058W from the 14.8V battery.

ESE S4 Embedded Systems H/W week 5 Worksheet – Power Calculations

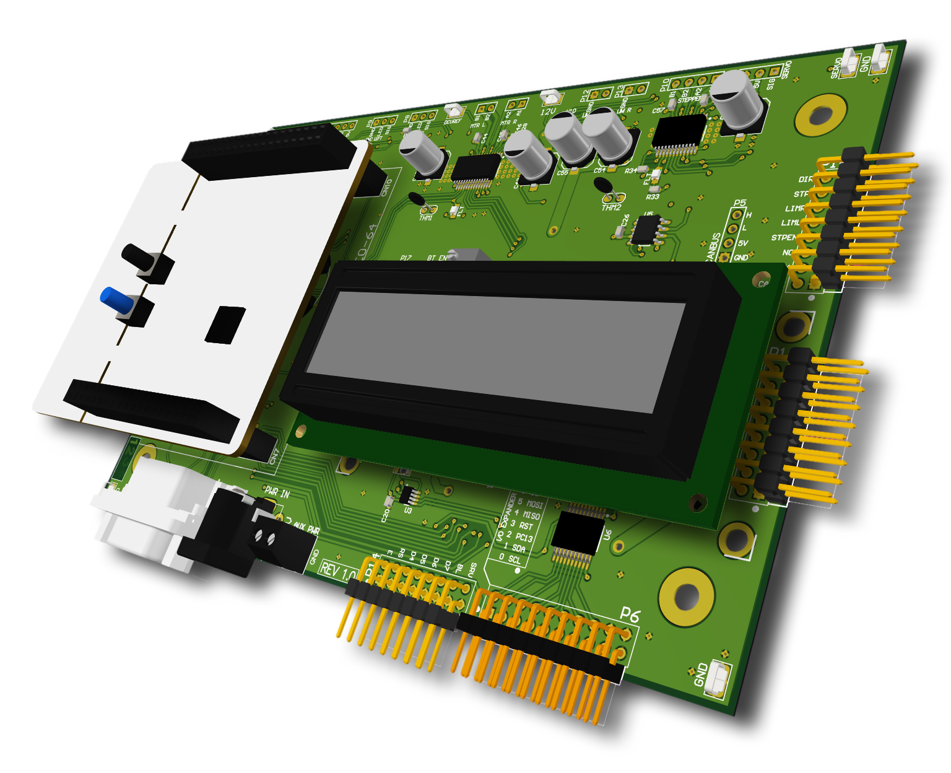
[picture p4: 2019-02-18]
Board.PNG

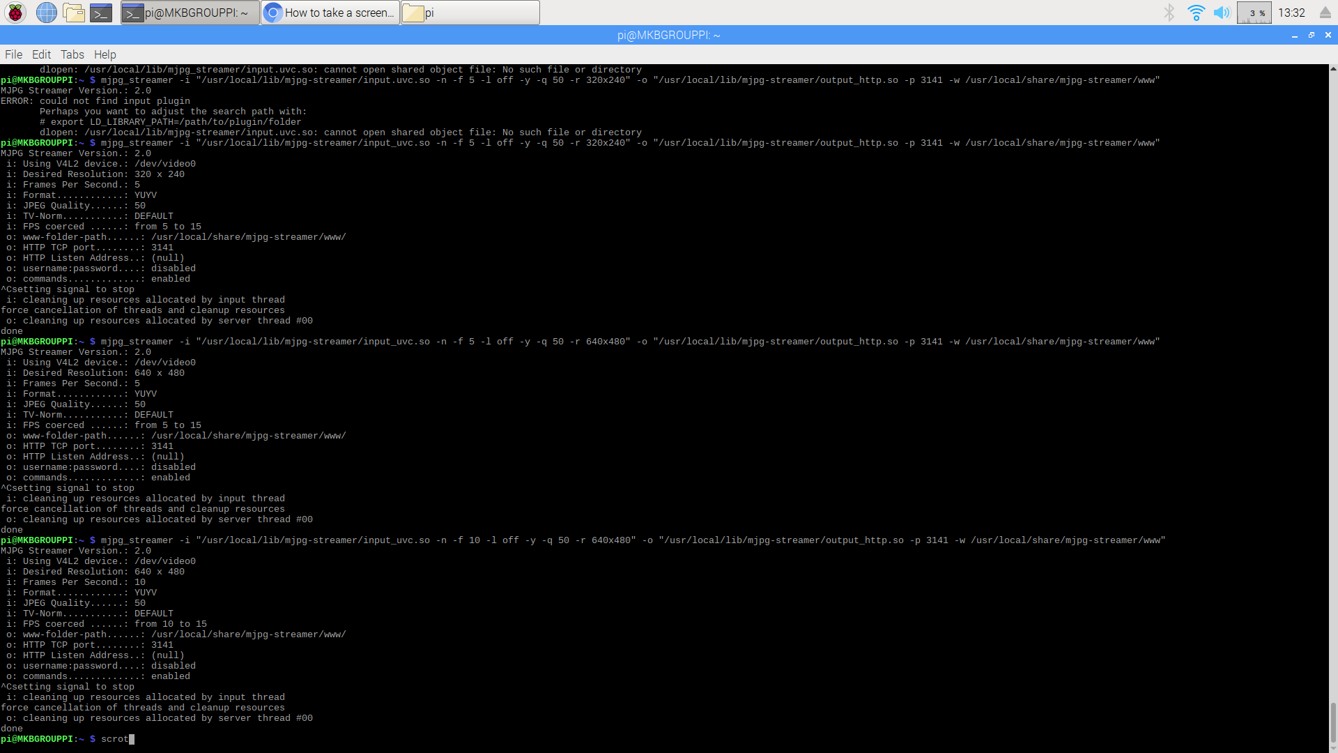
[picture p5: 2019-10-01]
Code/streamer cmd.png

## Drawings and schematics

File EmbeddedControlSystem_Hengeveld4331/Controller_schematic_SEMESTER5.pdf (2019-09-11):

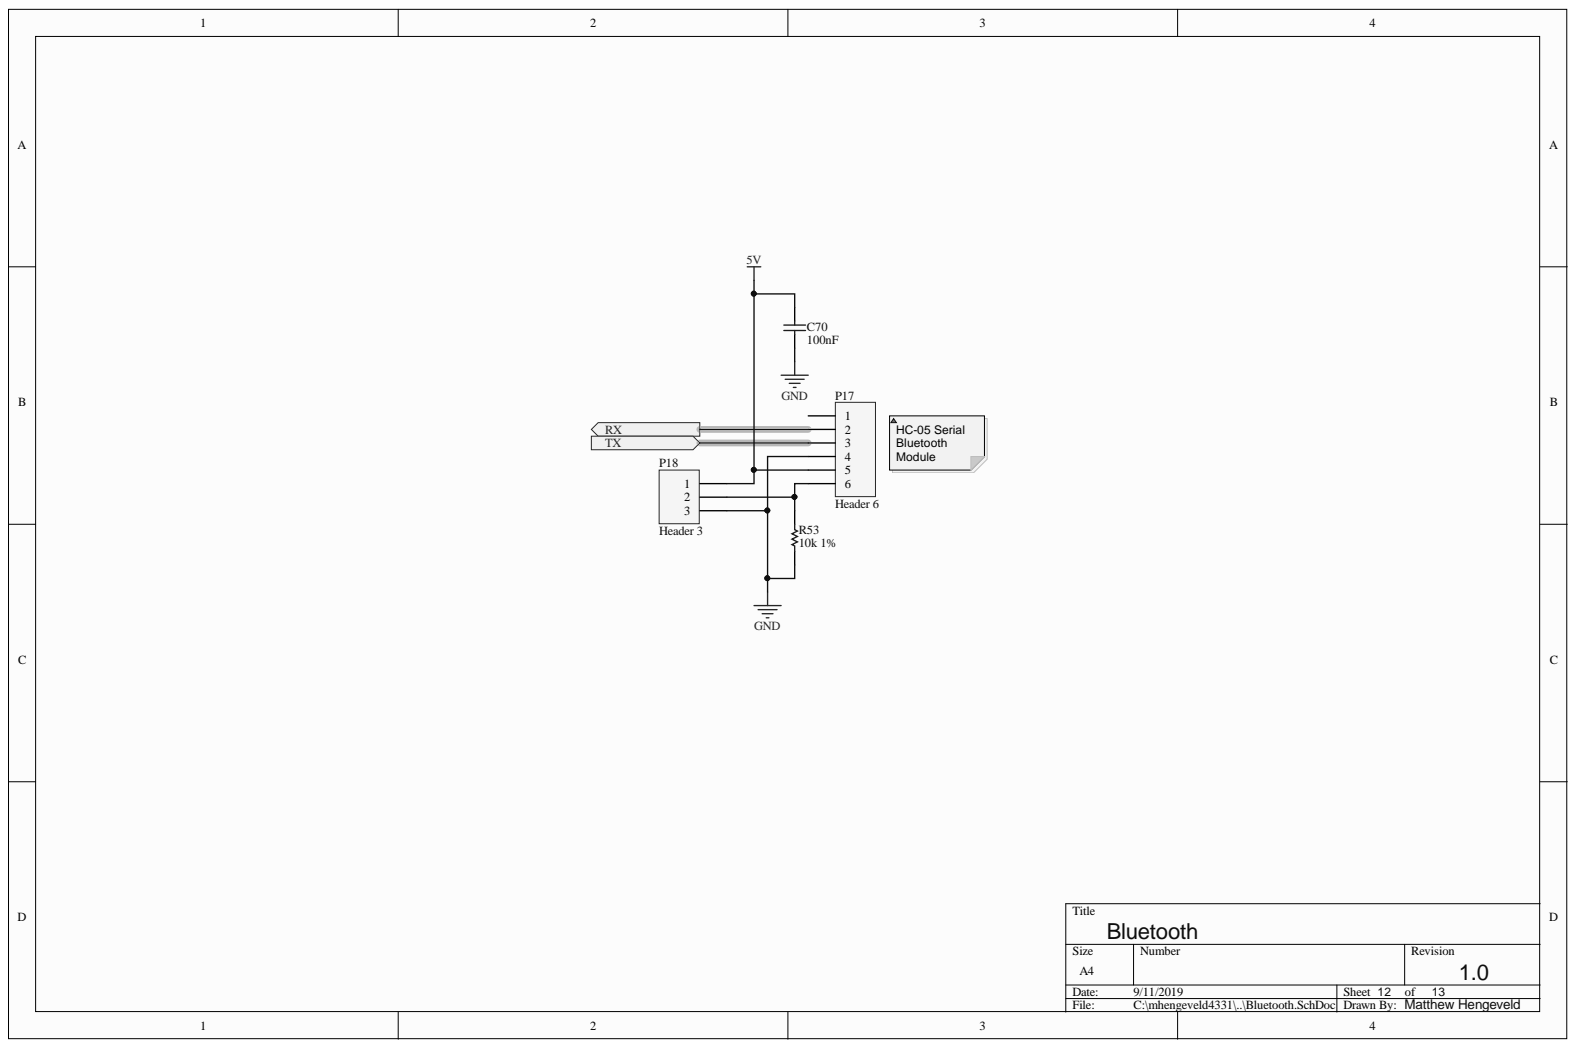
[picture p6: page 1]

Size A4 | Number | Revision 1.0

Date: 9/11/2019 | Sheet 12 of 13
File: C:\mhengeveld4331\..\Bluetooth.SchDoc | Drawn By: Matthew Hengeveld

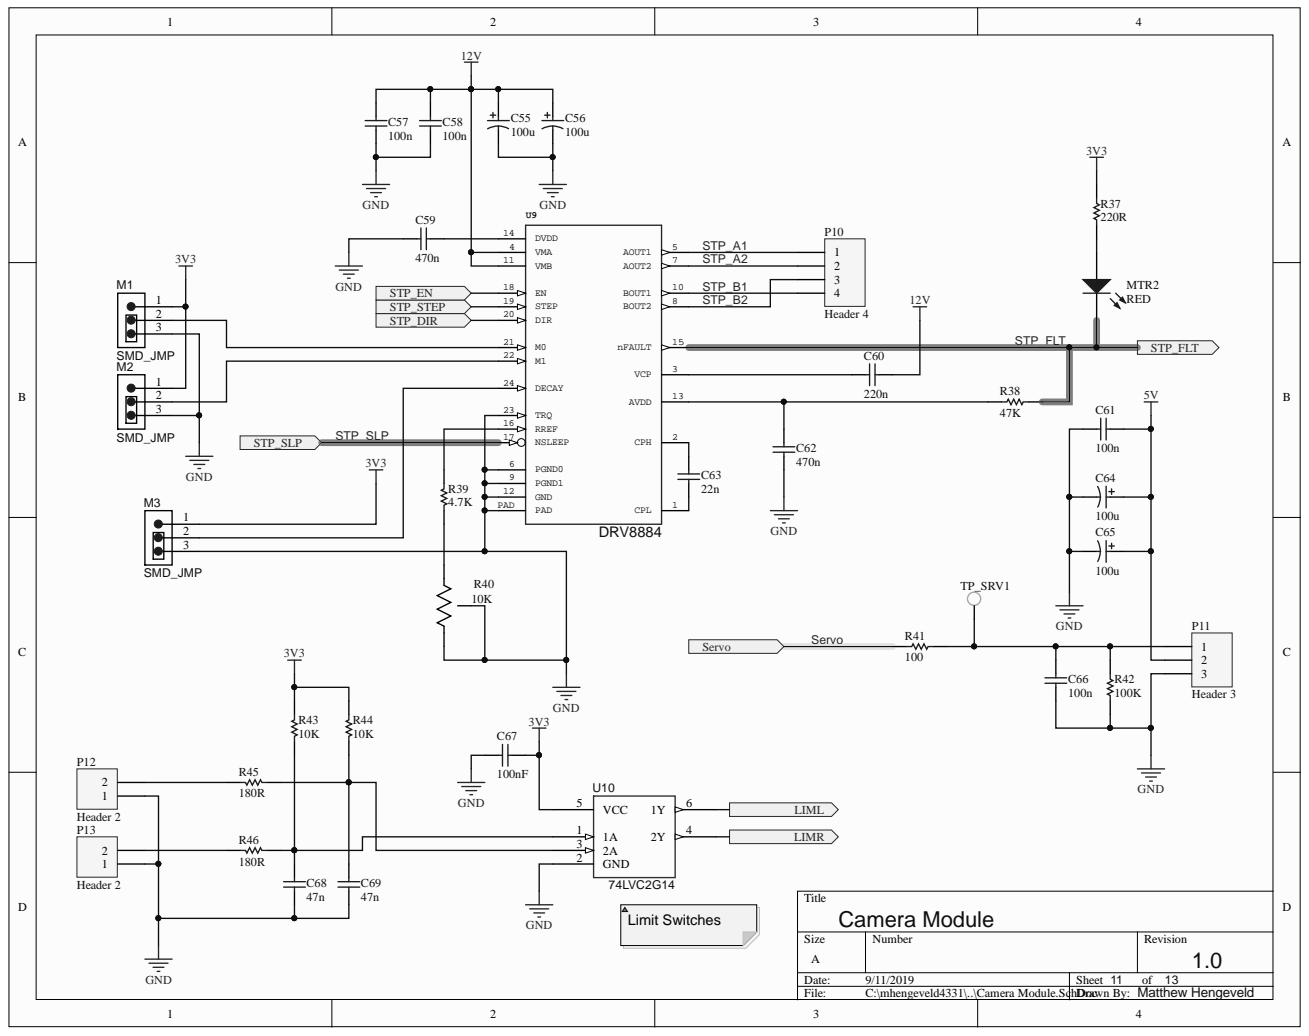
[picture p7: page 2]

STP_B1

STEP 19 | | STP_B2
DIR 20 M0 21 | Header 4

DECAY 24

TRQ 23
RREF 16
NSLEEP 17 PGND0 6

PGND1 9
GND 12
PAD

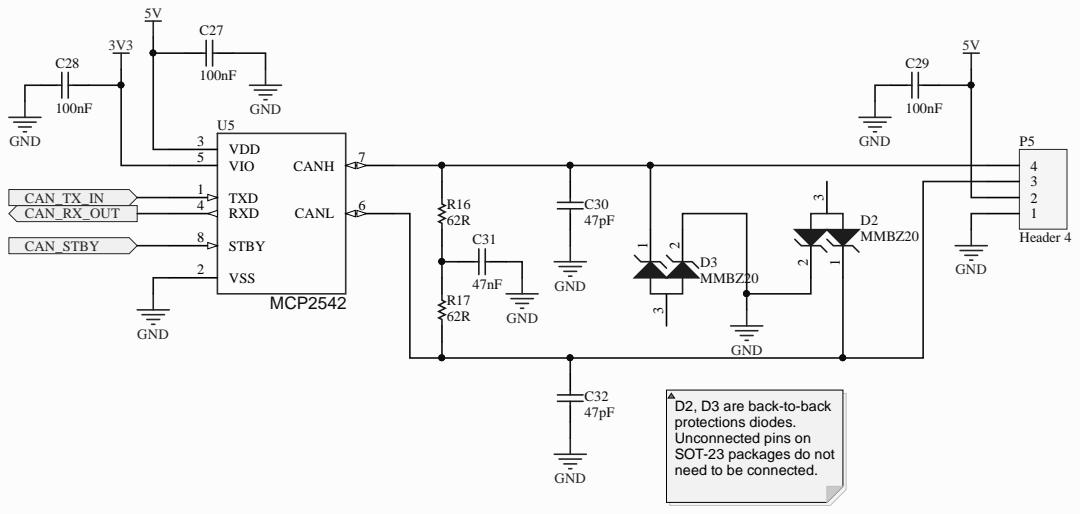
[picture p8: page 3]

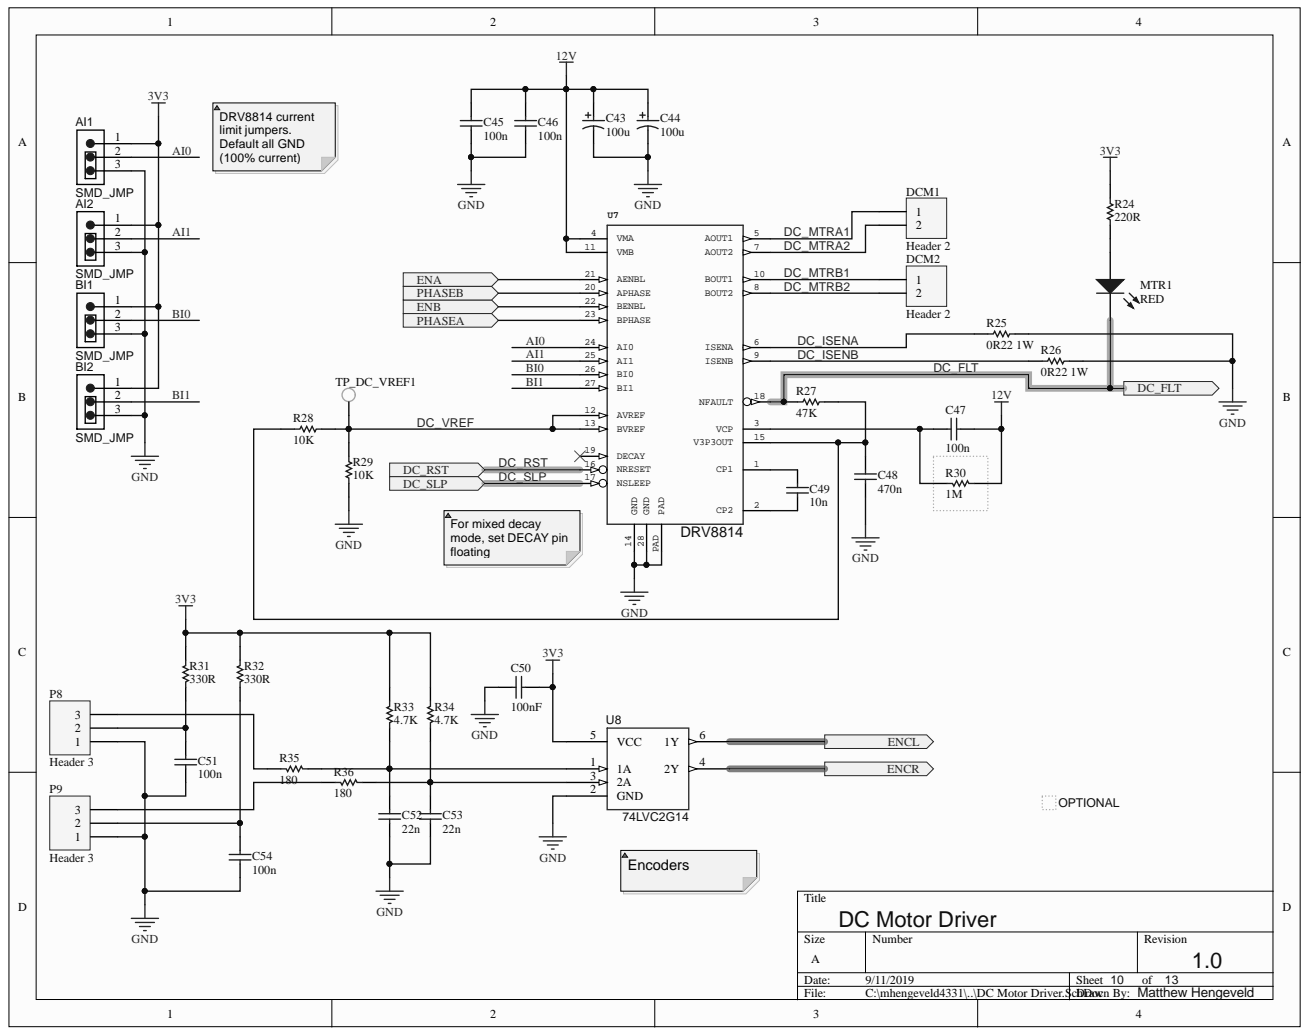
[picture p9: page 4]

DC_RST | V3P3OUT DECAY 19 CP1 | 15

NRESET 16 | R30 1M

For mixed decay
mode, set DECAY pin
floating

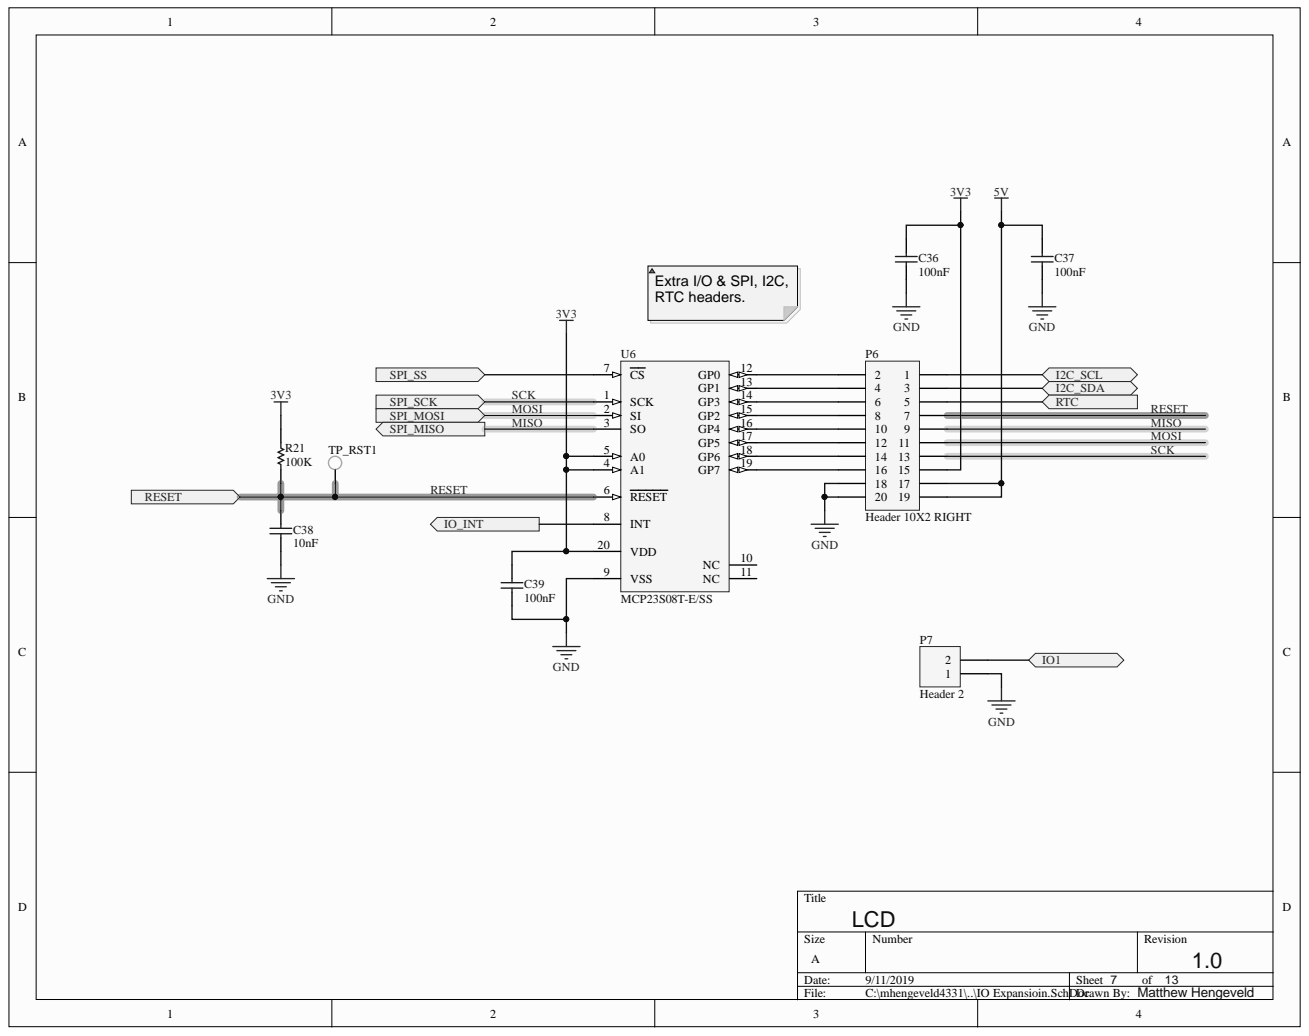
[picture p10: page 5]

RESET 6

INT 8 VDD 20

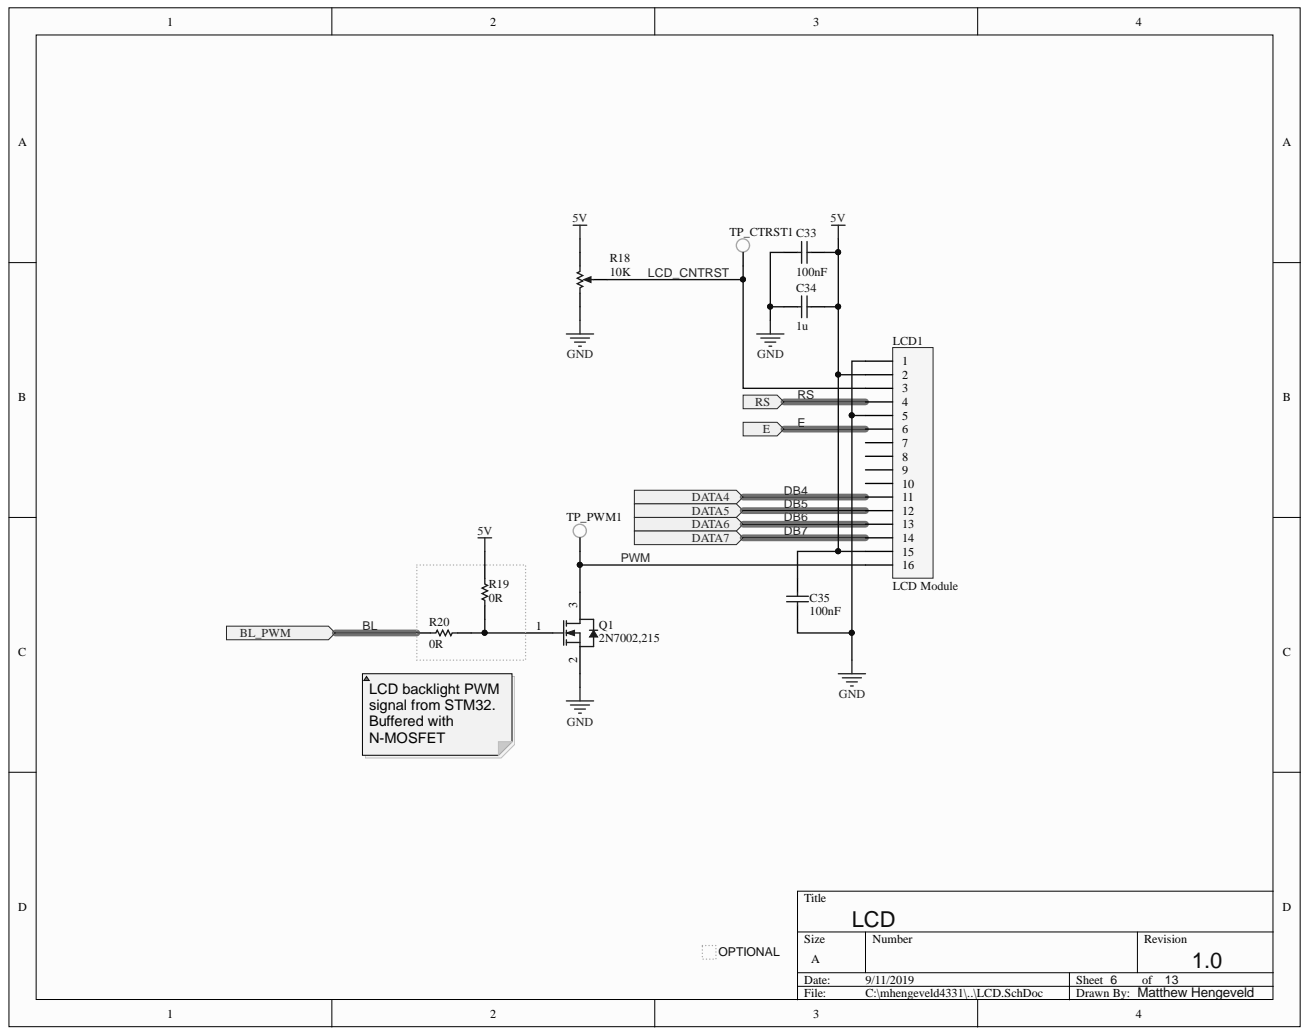
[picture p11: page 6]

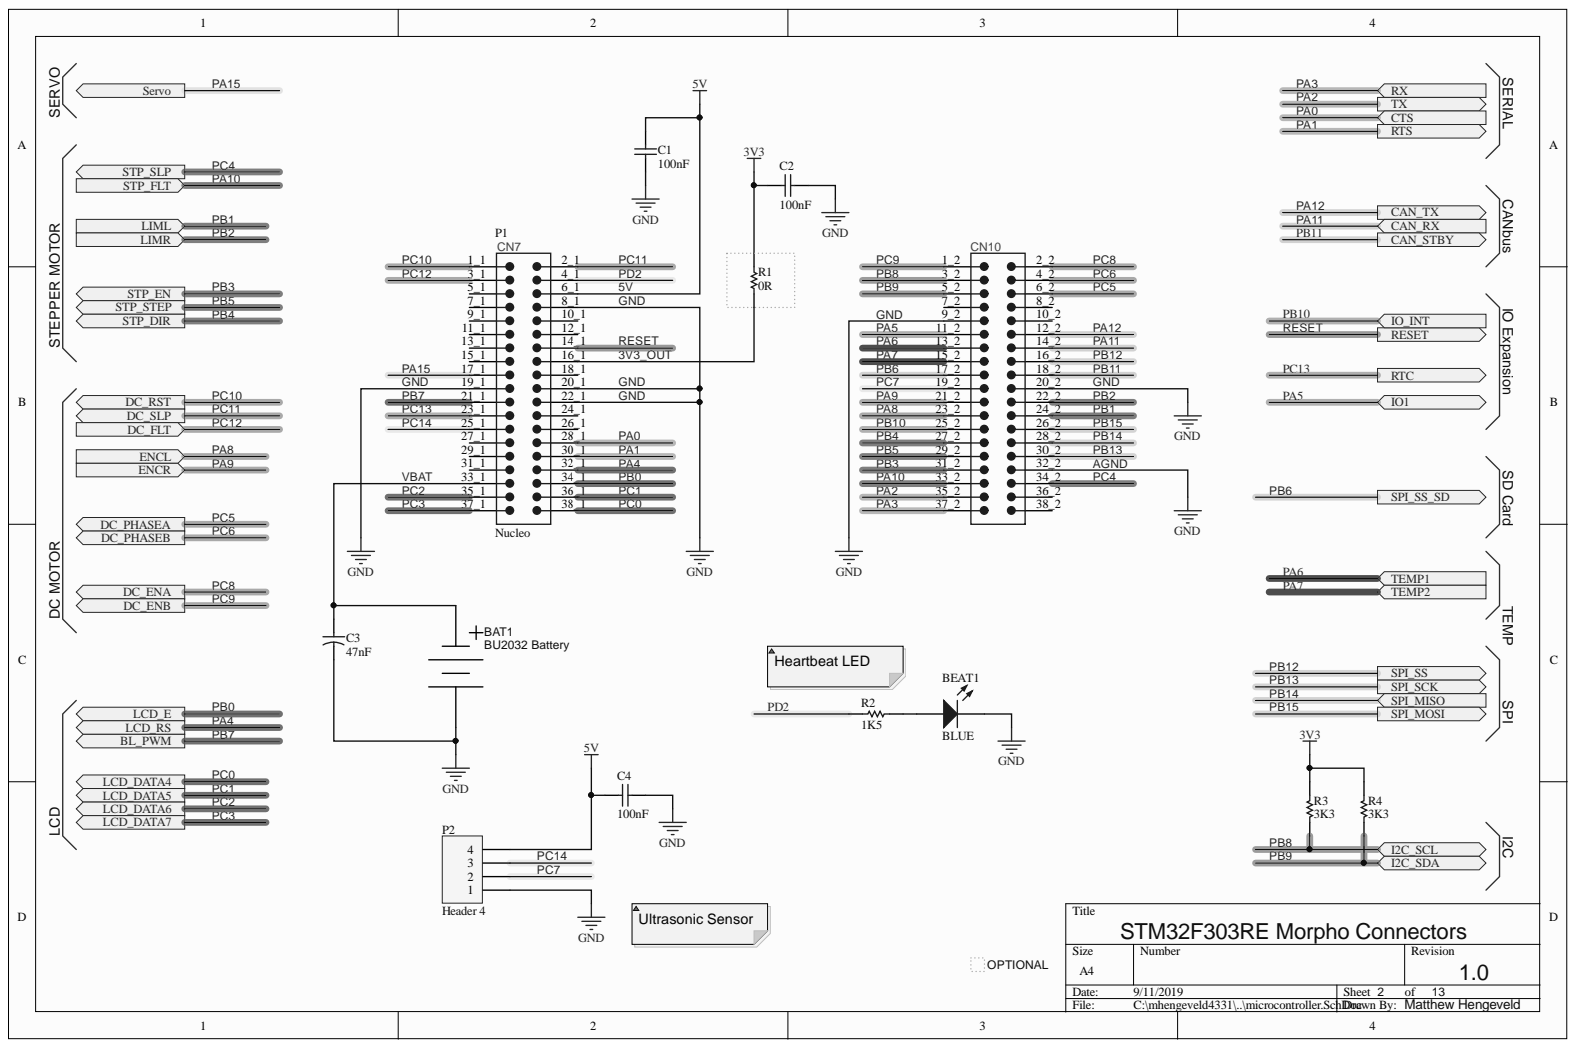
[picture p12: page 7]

SERVO STEPPER MOTOR DC MOTOR LCD

Numbe r | ectors1.0 Matthew Heng R evision

: 9/11/2019 | She et 2 of 13
File : C:\mhengeveld4331\. .\mic rocontrolle r . S chDDocrawn | By: eveld

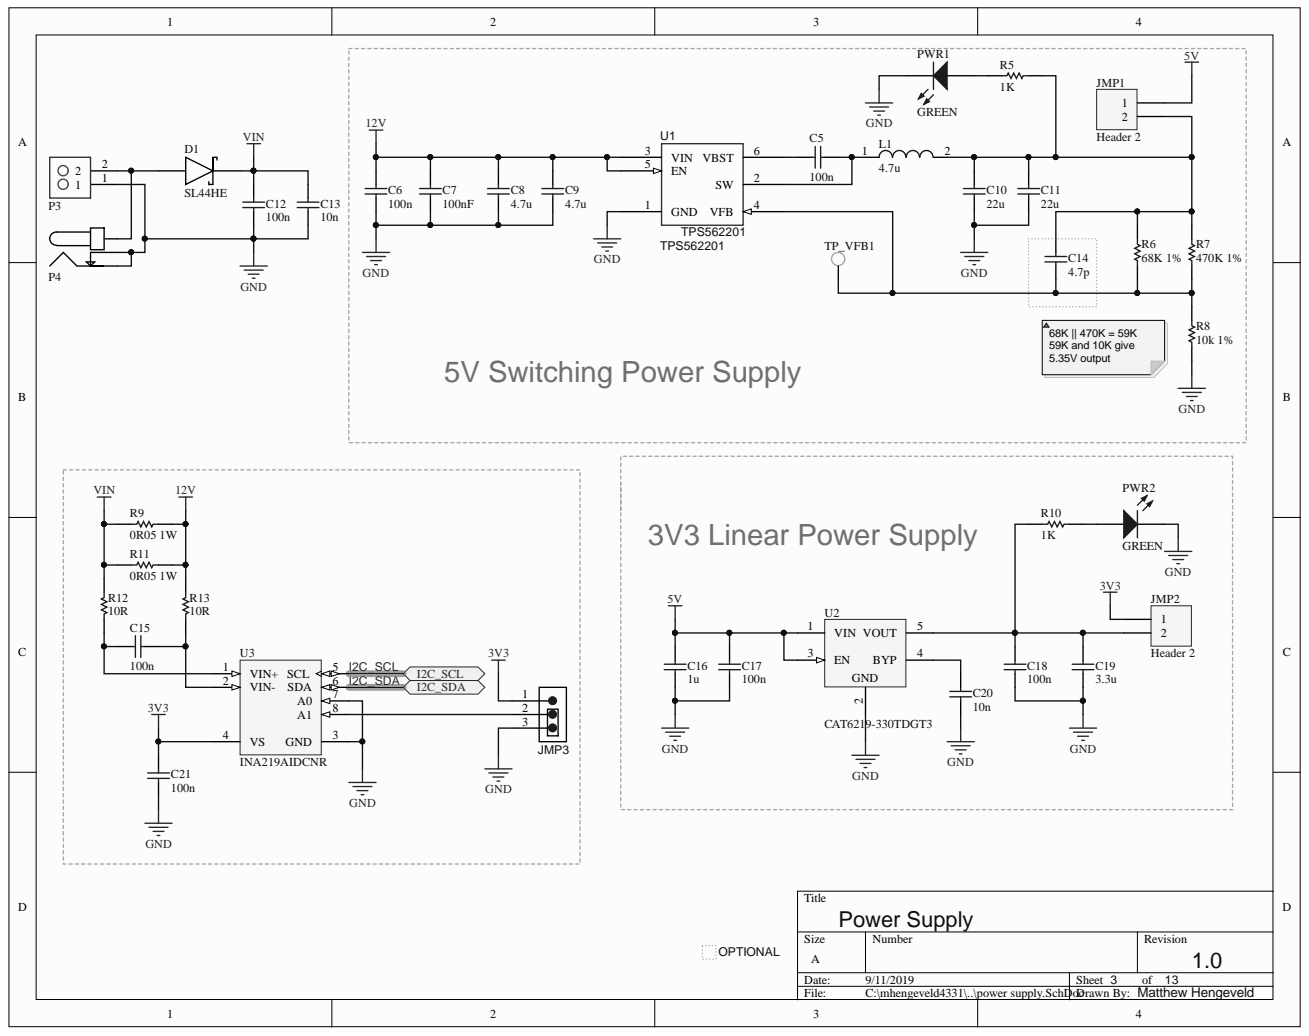
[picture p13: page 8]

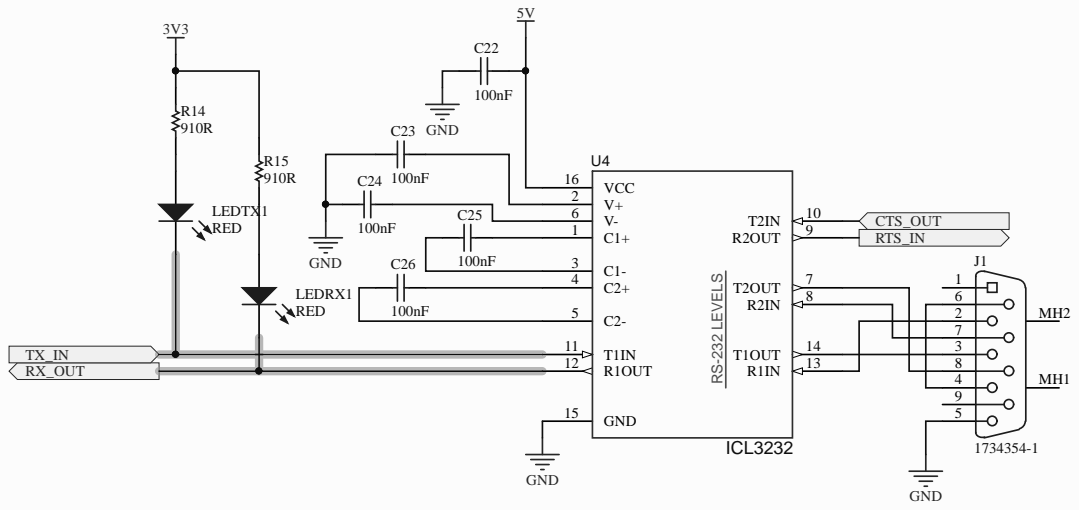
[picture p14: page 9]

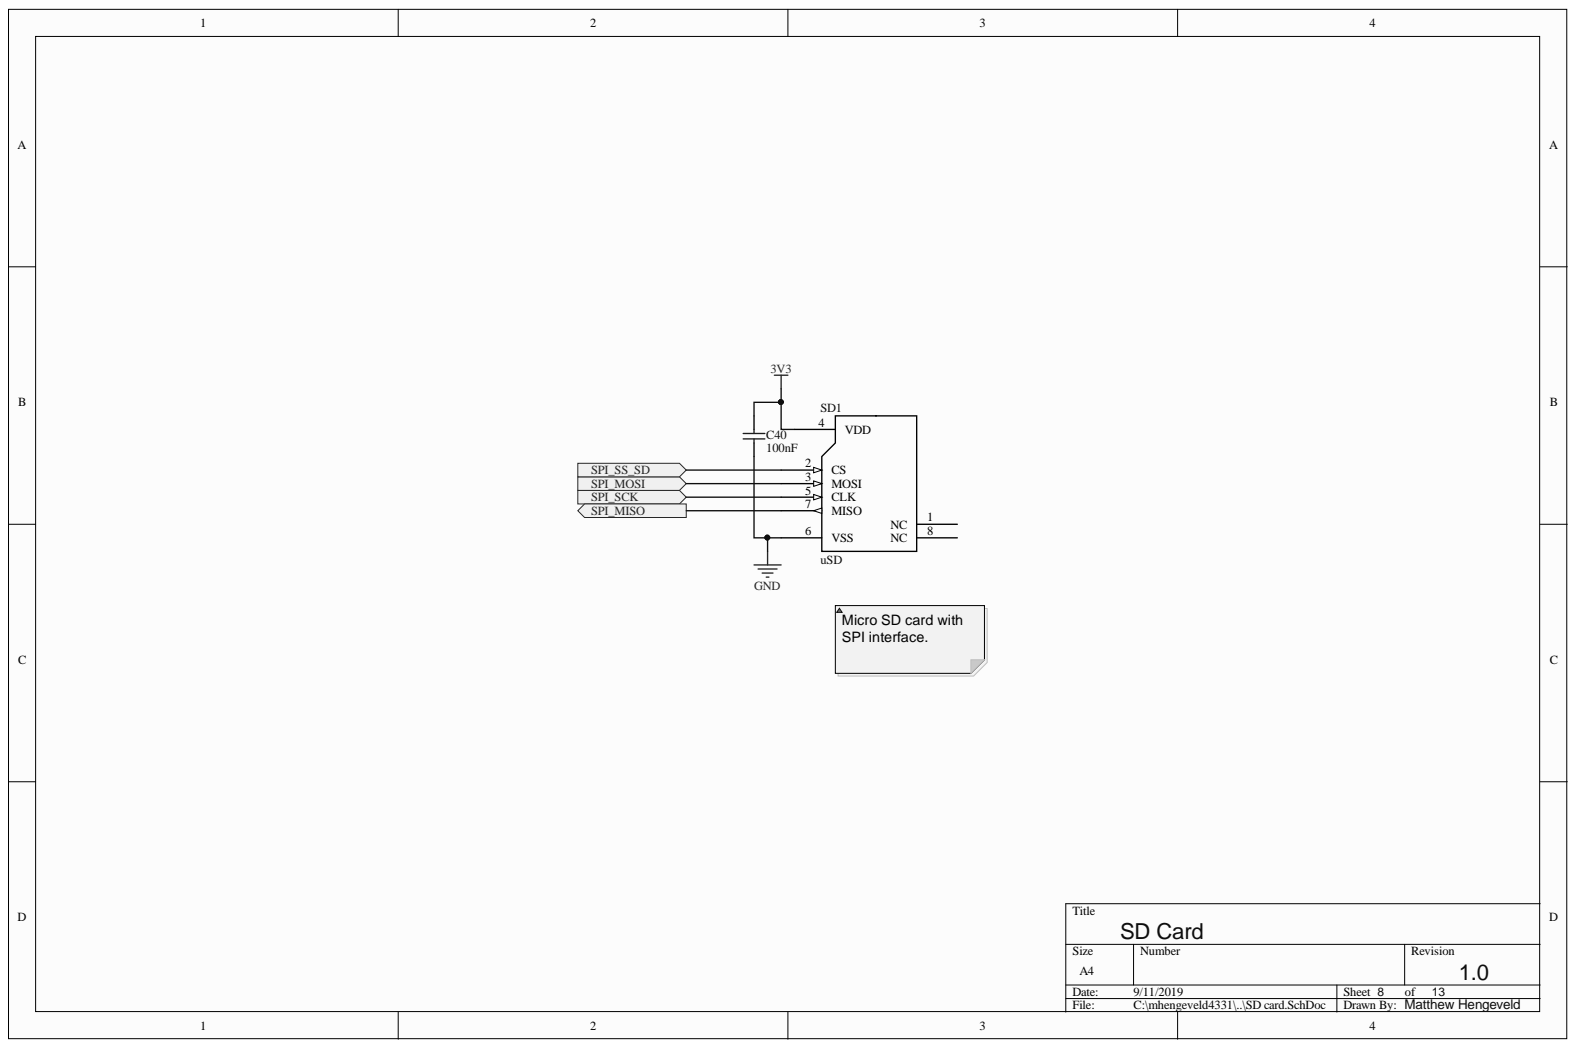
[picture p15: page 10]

Micro SD card with
SPI interface.

Size A4 | Number | Revision 1.0

Date: 9/11/2019 | Sheet 8 of 13
File: C:\mhengeveld4331\..\SD card.SchDoc | Drawn By: Matthew Hengeveld

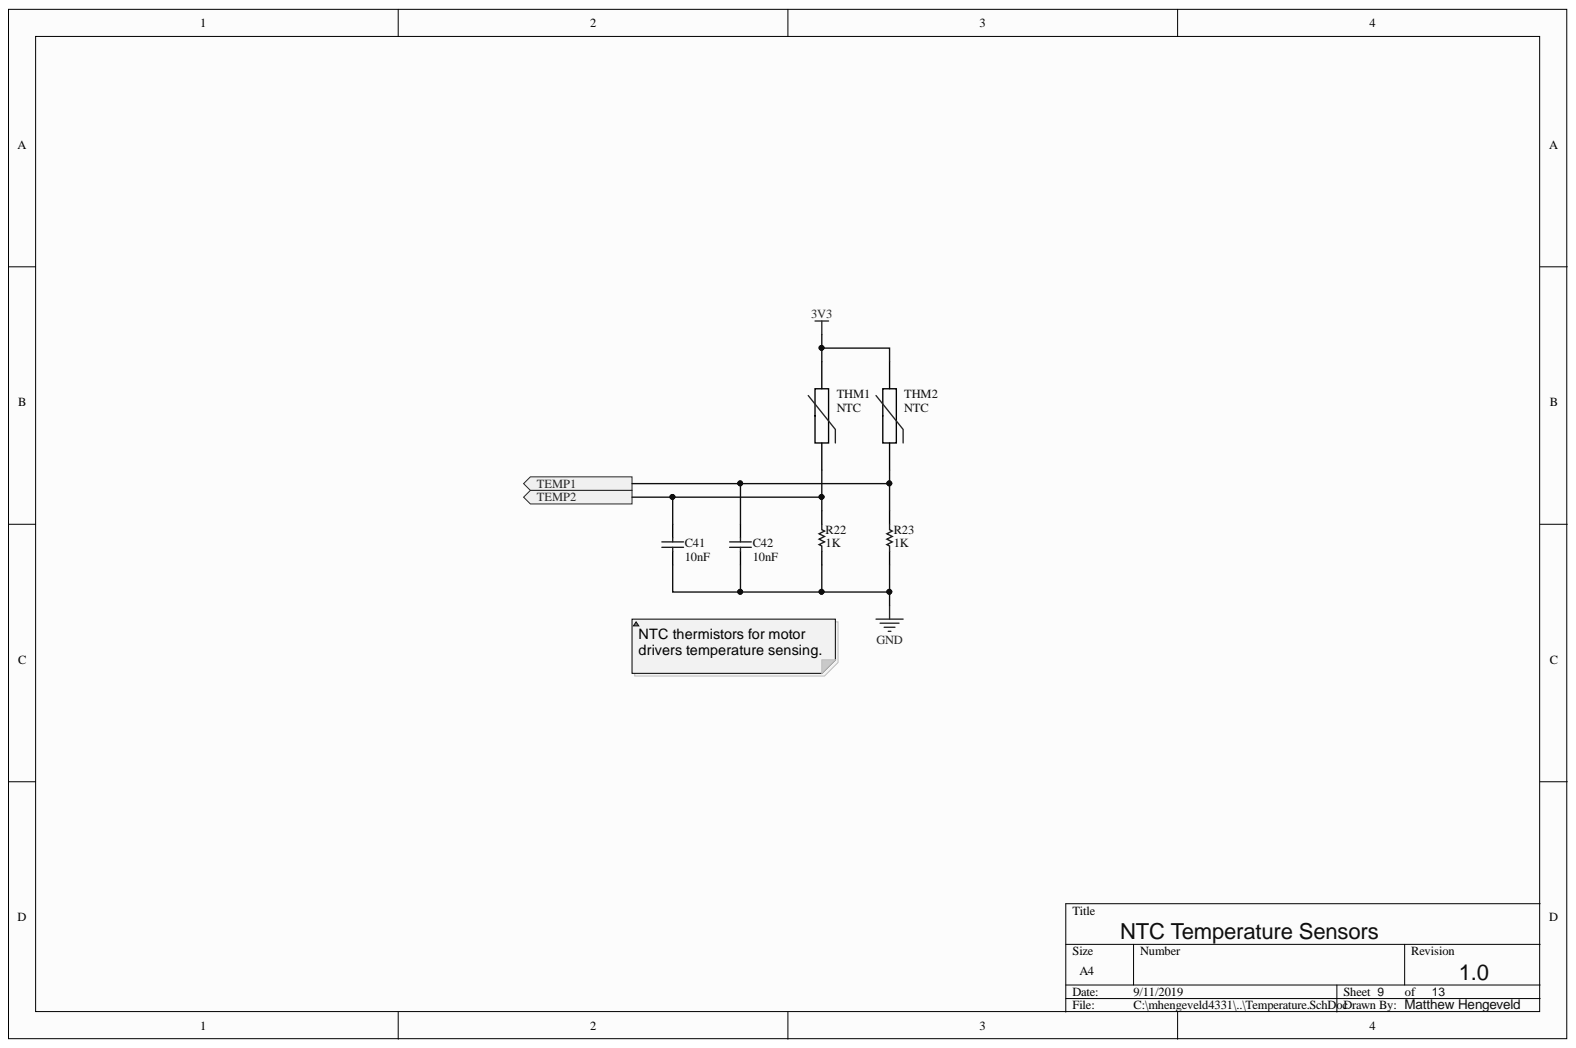
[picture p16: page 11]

NTC thermistors for motor
drivers temperature sensing.

Size A4 | Number | Revision 1.0

Date: 9/11/2019 | Sheet 9 of 13
File: C:\mhengeveld4331\..\Temperature.SchDocDrawn By: | Matthew Hengeveld

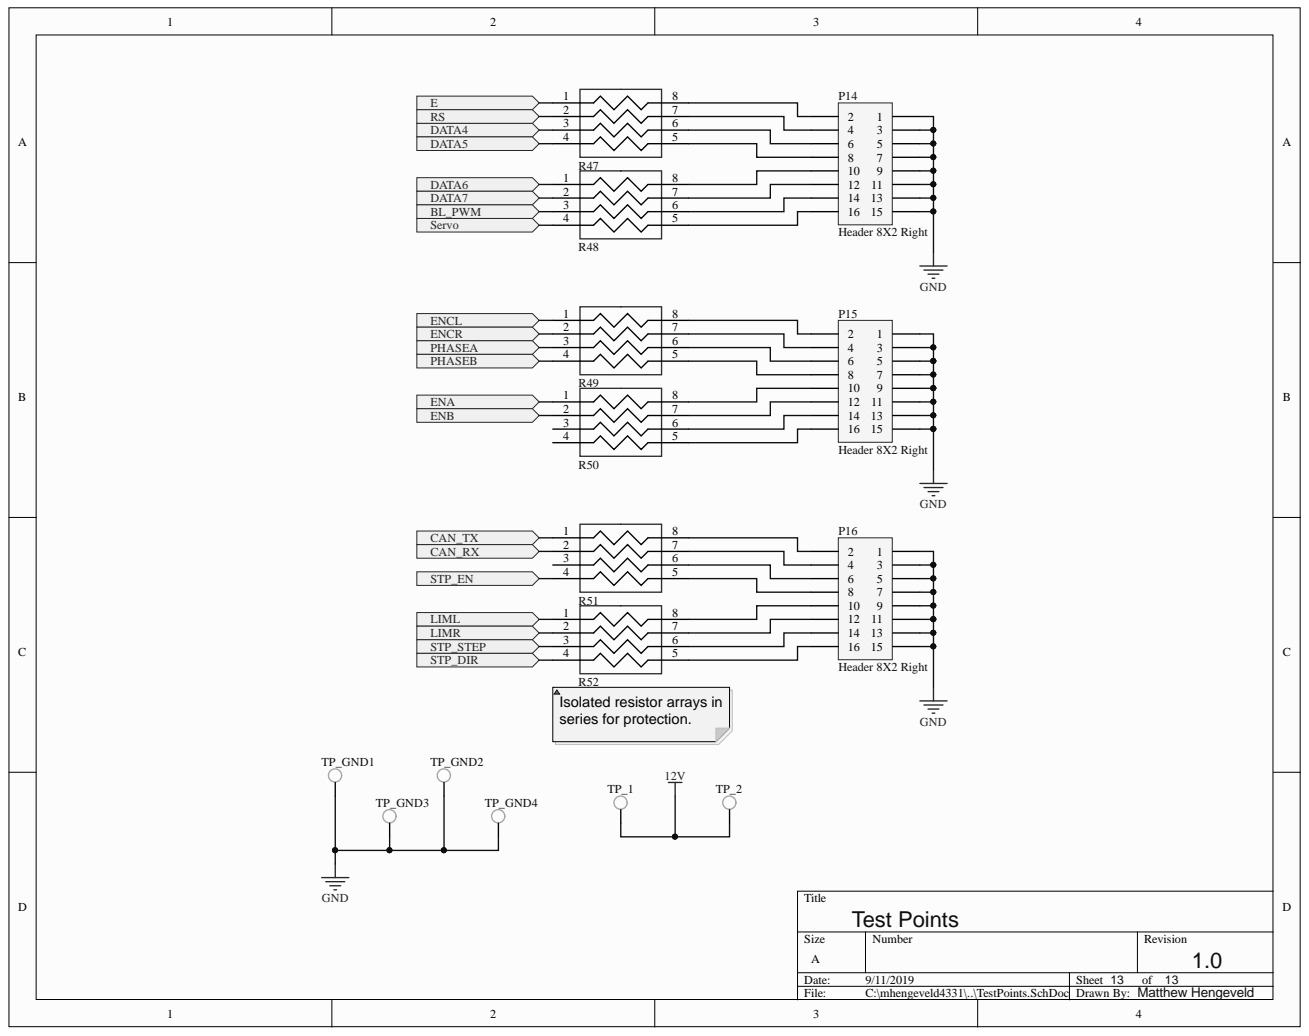
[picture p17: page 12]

Isolated resistor arrays in
series for protection.


DC Motor
DC Motor Driver.SchDoc

Size B | Number | Revision

Date: 9/11/2019 | Sheet 1 of 13
File: C:\mhengeveld4331\..\Top sheet.SchDoc | Drawn By:


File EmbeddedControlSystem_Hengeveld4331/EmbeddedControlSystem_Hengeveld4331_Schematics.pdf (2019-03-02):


DC Motor
DC Motor Driver.SchDoc

Size B | Number | Revision

Date: 2/22/2019 | Sheet 1 of 13
File: C:\ESE Conestoga\..\Top sheet.SchDoc | Drawn By:


SERVO STEPPER MOTOR DC MOTOR LCD

Numbe r | ectors1.0 Matthew Heng R evision

: 2/22/2019 | She et 2 of 13
File : C:\ESE Conestoga\. .\mic rocontrolle r . S chDocDr | a wn By: eveld






RESET 6

INT 8 VDD 20


Micro SD card with
SPI interface.

Size A4 | Number | Revision 1.0

Date: 2/22/2019 | Sheet 8 of 13
File: C:\ESE Conestoga\..\SD card.SchDoc | Drawn By: Matthew Hengeveld


NTC thermistors for motor
drivers temperature sensing.

Size A4 | Number | Revision 1.0

Date: 2/22/2019 | Sheet 9 of 13
File: C:\ESE Conestoga\..\Temperature.SchDoc Drawn By: | Matthew Hengeveld


For mixed decay
mode, set DECAY pin
floating

GND 2


STP_B1

STEP 19 | | STP_B2
DIR 20 M0 21 | Header 4

DECAY 24

TRQ 23
RREF 16
NSLEEP 17 PGND0 6

PGND1 9
GND 12
PAD


Size A4 | Number | Revision 1.0

Date: 2/22/2019 | Sheet 12 of 13
File: C:\ESE Conestoga\..\Bluetooth.SchDoc | Drawn By: Matthew Hengeveld


Isolated resistor arrays in
series for protection.




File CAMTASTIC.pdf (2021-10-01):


CAMtasticDXP (TM): controller.gto, controller.gtp, controller.gts, controller.gtl


CAMtasticDXP (TM): controller.g1, controller.g2, controller.gbl, controller.gbs


CAMtasticDXP (TM): controller.gbp, controller.gbo, controller.gm13, controller.gpt


CAMtasticDXP (TM): controller.gpb,
















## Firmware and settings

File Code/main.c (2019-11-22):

/* ------------------------------------------
// 	Name:		Matthew Hengeveld
//	ID:			8534331
//	Date:		1/17/2019
//
//	LEDs:
//		Green			PA5
//		HEARBEAT		PD2
//
//	-----------------------------------------*/

#include "utils.h"
#include <string.h>

#include "system_stm32f3xx.h"
#include "stm32f303xe.h"
#include "SysClock.h"
#include "SysTick.h"

#include "LEDs.h"
#include "LCD.h"
#include "DRV8884.h"
#include "lim_sw.h"
#include "servo.h"
#include "DRV8814.h"
#include "encoders.h"
#include "TIM15.h"
#include "serial.h"
#include "RTC.h"

#define	HEARTBEAT_TIMER_VAL			300000			// heartbeat LED timer
#define ENC_SW_ITER							10					// encoder switch iterations
#define SERVODEFAULT						1600				// default servo position

// stepper global variables
volatile static uint16_t step_num = 0;
volatile uint8_t step_fault = DRV8884_NO_FAULT;
volatile uint8_t step_fault_changed = 0;
uint16_t total_LR_steps = 0;	// total steps form left limit switch to right limit switch
uint16_t current_LR_steps = 0;
volatile static uint8_t stepper_dis_cnt = 0;

// servo global variables
volatile static uint16_t servo_angle_curr = SERVODEFAULT - 100;
volatile static uint16_t servo_angle = SERVODEFAULT;

// DC global variables
volatile uint8_t dc_fault = DRV8814_NO_FAULT;
volatile uint8_t dc_fault_changed = 0;
volatile uint8_t dc_speedL = 0;
volatile uint8_t dc_speedR = 0;
volatile uint8_t dc_dirL = 1;	// 0 - backwards; 1 - forwards
volatile uint8_t dc_dirR = 1;

// limit switch global variables
volatile static uint16_t Step_RLim = 0;
volatile static uint16_t Step_LLim = 0;

// encoder global variables
volatile static uint16_t speed_R = 0;
volatile static uint16_t speed_L = 0;
volatile static uint8_t enc_update = 0;	// Encoder update flag

// LCD & Serial update flag
volatile static uint8_t update_flag = 0;
volatile static uint8_t send_update = 2;
#define STATUSMSGLEN		13

// Serial UART global variables
volatile static uint8_t SerialRX_Buf[64];
volatile static uint8_t SerialRX_Buf_index = 0;
volatile static uint8_t SerialRX_cmd[64];
volatile static uint8_t cmd_recv = 0;
volatile static uint8_t cmd_recv_index = 0;

void send_status(void);

void TIM16_IRQHandler(void) {
	if ((TIM16->SR & TIM_SR_UIF) != 0) {
		if (step_num > 0) {
			step_num--;
									
			DRV8884_STEP_HI;
			uint32_t wait = 50;
			while (wait--);
			DRV8884_STEP_LO;
			
		}
		
		if (servo_angle > servo_angle_curr) {
			if ((servo_angle - servo_angle_curr) < 2) {
				servo_angle_curr = servo_angle;
			} else {
				servo_angle_curr += 2;
			}
			Servo_set_us(servo_angle_curr);
		} else if (servo_angle < servo_angle_curr) {
			if ((servo_angle_curr - servo_angle) < 2) {
				servo_angle_curr = servo_angle;
			} else {
				servo_angle_curr -= 2;
			}
			Servo_set_us(servo_angle_curr);
		}
		
		TIM16->SR &= ~TIM_SR_UIF;
	}
}

void TIM15_IRQHandler(void) {
	if ((TIM15->SR & TIM_SR_UIF) != 0) {
		
		update_flag = 1;
		
		send_update--;
		
		Step_LLim = 0;
		Step_RLim = 0;
		
		if (step_num == 0) {
			stepper_dis_cnt--;
			if (stepper_dis_cnt < 1) {
				stepper_dis_cnt = 1;
			}
			if (stepper_dis_cnt == 2) {
				DRV8884_disable();
			}
		} else {
			stepper_dis_cnt = 30;
		}
		
		TIM15->SR &= ~TIM_SR_UIF;
	}
}

// R Limit switch interrupt handler
void EXTI2_TSC_IRQHandler(void) {

	Step_LLim = 1;
	
	SET_BITS(EXTI->PR, EXTI_PR_PIF2);	// clear EXTI2 flag
}

// L Limit switch interrupt handler
void EXTI1_IRQHandler(void) {

	Step_RLim = 1;
	
	SET_BITS(EXTI->PR, EXTI_PR_PIF1);	// clear EXTI1 flag
}

// Stepper motor driver fault pin
void EXTI3_IRQHandler(void) {
	if (!DRV8884_FLT_STATUS) {	// fault
		//DRV8884_disable();
		step_num = 0;
		step_fault = DRV8884_FAULT;
	} else {		// fault cleared
		DRV8884_enable();
		step_fault = DRV8884_NO_FAULT;
	}
	
	step_fault_changed = 1;
	
	SET_BITS(EXTI->PR, EXTI_PR_PIF3);	// clear EXTI3 flag
}

// DC motor driver fault pin
void EXTI4_IRQHandler(void) {
	if (!DRV8814_FLT_STATUS) {	// fault
		DRV8814_disable();
		dc_fault = DRV8814_FAULT;
	} else {		// fault cleared
		DRV8814_enable();
		dc_fault = DRV8814_NO_FAULT;
	}
	
	dc_fault_changed = 1;
	
	SET_BITS(EXTI->PR, EXTI_PR_PIF4);	// clear EXTI12 flag
}

// encoder interrupt
void TIM1_CC_IRQHandler(void) {
		
	if (TIM1->SR & TIM_SR_CC1IF) {
	
		speed_R = 1000000 / ((TIM1->CCR1*2)+1);	// save value and clear interrupt
		enc_update = 2;
		
		CLR_BITS(TIM1->CCER,TIM_CCER_CC1E);	// disable capture from counter channel 1 --default--
		SET_BITS(TIM1->CCER,TIM_CCER_CC2E);	// enable capture from counter channel 2
		
		CLR_BITS(TIM1->DIER,TIM_DIER_CC1IE);	// disable interrupt channel 1 --default--
		SET_BITS(TIM1->DIER,TIM_DIER_CC2IE);	// enable interrupt channel 2
		
		speed_L = 0;
	} 
	if (TIM1->SR & TIM_SR_CC2IF) {
		
		speed_L = 1000000 / ((TIM1->CCR2*2)+1);	// save value and clear interrupt
		enc_update = 1;
		
		SET_BITS(TIM1->CCER,TIM_CCER_CC1E);	// enable capture from counter channel 1 --default--
		CLR_BITS(TIM1->CCER,TIM_CCER_CC2E);	// disable capture from counter channel 2
		
		SET_BITS(TIM1->DIER,TIM_DIER_CC1IE);	// enable interrupt channel 1 --default--
		CLR_BITS(TIM1->DIER,TIM_DIER_CC2IE);	// disable interrupt channel 2
		
		speed_R = 0;
	}
	
	//CLR_BITS(TIM1->SR, TIM_SR_UIF);
	
}

// Serial UART Receive ISR
void USART2_IRQHandler(void) {
	SerialRX_Buf[SerialRX_Buf_index] = USART2->RDR;
	
	if (SerialRX_Buf[SerialRX_Buf_index] == 'X') {
		memcpy((void*)SerialRX_cmd, (void*)SerialRX_Buf, 64);
		
		cmd_recv = 1;
		if (SerialRX_Buf_index > 0) {
			cmd_recv_index = SerialRX_Buf_index - 1;
		} else {
			cmd_recv_index = 63;
		}
;
	}
		
	SerialRX_Buf_index++;
	if (SerialRX_Buf_index == 64) {
		SerialRX_Buf_index = 0;
	}
}

uint16_t CAM_HOME(void) {
	LCDsetCursorPosition(2, 0);
	LCDprintf("HOMING");
	delay_ms(5);
	
	DRV8884_DIR_CW;
	step_num = 1500;
	DRV8884_enable();
	DRV8884_wake();
	while (Step_RLim == 0);	// turn until right limit is hit
	
	uint16_t total_steps = 0;	// set steps count to 0
	
	DRV8884_DIR_CCW;
	DRV8884_enable();
	DRV8884_wake();
	step_num = 1500;
	while (Step_LLim == 0);
	total_steps = 1500 - step_num;
	step_num = 0;	//stop
	
	DRV8884_enable();
	DRV8884_wake();
	DRV8884_DIR_CW;
	step_num = total_steps >> 1;
	
	while (step_num);	// wait for stepper to get to middle
	
	DRV8884_disable();
	
	// done homing stepper
	
	/// home servo
	Servo_set_us(servo_angle);
	
	LCDsetCursorPosition(2, 0);
	LCDprintf("      ");
	delay_ms(5);
	
	return total_steps+40;
}

void send_status(void) {
	char status_msg[STATUSMSGLEN];
	
	status_msg[0] = 'X';
	status_msg[1] = 'S';
	status_msg[2] = 'T';
	status_msg[3] = servo_angle;
	status_msg[4] = LO_NIBBLE(current_LR_steps);
	status_msg[5] = HI_NIBBLE(current_LR_steps);
	status_msg[6] = speed_R;
	status_msg[7] = dc_speedR;
	status_msg[8] = dc_dirR;
	status_msg[9] = speed_L;
	status_msg[10] = dc_speedL;
	status_msg[11] = dc_dirL;
	status_msg[12] = '\n';
	
	UART_puts(status_msg);
}

int main(void){

	// system clock
	System_Clock_Init(); // Switch System Clock = 72MHz
	
	// systick
	SysTick_Init(SYSTICK_US_VAL);
	
	// LCD
	LCD_Init();
	LCDclear();

	// hearbeat LED
	Heartbeat_Init();
	LED_Init();
	uint32_t beat_timer = HEARTBEAT_TIMER_VAL;
	
	LCDprintf("Matt H - ESE Yr2");
	
	delay_ms(500);
	
	LCDclear();
	LCDsetCursorPosition(1, 0);
	LCDprintf("STEP");
	LCDsetCursorPosition(1, 14);
	LCDprintf("DC");
	
	// limit switches
	lim_sw_Init();
	
	// stepper motor
	DRV8884_Init();
	DRV8884_sleep();
	DRV8884_DIR_CW;
	DRV8884_disable();
	step_fault = DRV8884_NO_FAULT;
	step_fault_changed = 0;
	
	// servo
	Servo_Init(SERVOFREQ, SERVO_FWD_DEG);
	Servo_set(servo_angle);
	
	// DRV8814
	DRV8814_Init();
	DRV8814_sleep();
	DRV8814_disable();
	dc_fault = DRV8814_NO_FAULT;
	dc_fault_changed = 0;
	//short int dc_step = 1;
	DRV8814_wake();
	DRV8814_enable();
	
	// encoders
	ENC_Init();
	TIM15_Init(8000000);
	
	// serial
	UART_Init(SERIAL_BAUD_DEFAULT);
	
	// RTC
	RTC_Init();
	
	delay_ms(5);
	
	TIM17_set(LCD_BL_PWMFREQ, 80);
	
	total_LR_steps = CAM_HOME();
	
	while(1){
		
		// heartbeat LED toggles
		beat_timer--;
		if ((beat_timer == (HEARTBEAT_TIMER_VAL/21)) || (beat_timer == (HEARTBEAT_TIMER_VAL/24)) || (beat_timer == (HEARTBEAT_TIMER_VAL/60))) {
			HEARTBEAT_TOGGLE;
		} else if (beat_timer == 0) {
			HEARTBEAT_TOGGLE;
			beat_timer = HEARTBEAT_TIMER_VAL;
		}
		
		if (send_update < 3) {
			send_status();
			send_update = 53;
		}
		
		if (update_flag == 1) {
			if (step_fault == DRV8884_FAULT) {
				LCDsetCursorPosition(2, 0);
				LCDprintf("FLT!");
				
				UART_printf("STP FLT!");
			} else {
				LCDsetCursorPosition(2, 0);
				LCDprintf("    ");
			}
			
			if (dc_fault == DRV8814_FAULT) {
				LCDsetCursorPosition(2, 11);
				LCDprintf("FLT!");
				
				UART_printf("STP FLT!");
			} else {
				if (enc_update == 2) {
					LCDsetCursorPosition(2, 10);
					if (speed_R < 100) {
						LCDprintf(" %uHz",speed_R);
					} else {
						LCDprintf("%uHz",speed_R);
					}
					enc_update = 0;
				}
				
			}
			update_flag = 0;
		}
		
		if (cmd_recv) {
			uint8_t cmd_recv_index_next;
			if (cmd_recv_index_next > 0) {
			cmd_recv_index_next = cmd_recv_index - 1;
		} else {
			cmd_recv_index_next = 63;
		}
			
			if (SerialRX_cmd[cmd_recv_index] == 'C') {
				switch (SerialRX_cmd[cmd_recv_index_next]) {
					
					case 'S':	//camera straight
						TIM16_Init(STEP_PWMFREQFAST);
					
						if (current_LR_steps > (total_LR_steps >> 1)) {
							DRV8884_DIR_CW;
						} else {
							DRV8884_DIR_CCW;
						}
						step_num = 1500;
						DRV8884_enable();
						DRV8884_wake();
						while ((Step_RLim == 0) && (Step_LLim == 0));	// turn until right limit is hit
					
						if (current_LR_steps > (total_LR_steps >> 1)) {
							DRV8884_DIR_CCW;
						} else {
							DRV8884_DIR_CW;
						}
						DRV8884_enable();
						DRV8884_wake();
						step_num = total_LR_steps >> 1;
						//while (step_num);
						
						servo_angle = SERVODEFAULT;
					
						break;
					
					case 'L':	//camera left
						TIM16_Init(STEP_PWMFREQMED);	
					
						if ((current_LR_steps - 40) > 0) {
							DRV8884_DIR_CCW;
							step_num = 41;
							DRV8884_enable();
							DRV8884_wake();
							current_LR_steps-= 40;
						}

						break;
					
					case 'R':	//camera right
						TIM16_Init(STEP_PWMFREQMED);	
					
						if ((current_LR_steps + 40) < total_LR_steps) {
							DRV8884_DIR_CW;
							step_num = 40;
							DRV8884_enable();
							DRV8884_wake();
							current_LR_steps+= 40;
						}
					
						break;
					
					case 'U':	//camera up
						
						servo_angle -= 60;
						if (servo_angle < SERVOMINDEG) {
							servo_angle = SERVOMINDEG;
						}
						//Servo_set(servo_angle);
						
						break;
					
					case 'D':	//camera down
						
						servo_angle += 60;
						if (servo_angle > SERVOMAXDEG) {
							servo_angle = SERVOMAXDEG;
						}
						//Servo_set(servo_angle);
					
						break;
				}
			} else if (SerialRX_cmd[cmd_recv_index] == 'H') {
				switch (SerialRX_cmd[cmd_recv_index_next]) {
					
					case 'L':	//hard left
						
						break;
					
					case 'R':	//hard right
						
						break;
					
					case 'M':	//home
						TIM16_Init(STEP_PWMFREQFAST);
						total_LR_steps = CAM_HOME();
						current_LR_steps = total_LR_steps >> 1;
						break;
				}
			} else if (SerialRX_cmd[cmd_recv_index] == 'R') {
				switch (SerialRX_cmd[cmd_recv_index_next]) {
					
					case 'S':	//robot stop
						
						dc_speedL = 0;
						dc_speedR = 0;
					
						DRV8814_set_speed_left(dc_speedL);
						DRV8814_set_speed_right(dc_speedR);
					
						break;
					
					case 'M':	//robot move
						
						if (SerialRX_cmd[cmd_recv_index-3] == 'F') {	// forward
							DRV8814_DIRL_FWD;
							dc_dirL = 1;
						} else {
							DRV8814_DIRL_BKWD;
							dc_dirL = 0;
						}
						dc_speedL = SerialRX_cmd[cmd_recv_index-2];
						if (dc_speedL > 99) {
							dc_speedL = 107;
						}
						
						DRV8814_set_speed_left(dc_speedL);
						
						if (SerialRX_cmd[cmd_recv_index-5] == 'F') {	// forward
							DRV8814_DIRR_FWD;
							dc_dirR = 1;
						} else {
							DRV8814_DIRR_BKWD;
							dc_dirR = 0;
						}
						dc_speedR = SerialRX_cmd[cmd_recv_index-4];
						if (dc_speedR > 99) {
							dc_speedR = 107;
						}
						
						DRV8814_set_speed_right(dc_speedR);

						break;
				}
			} else if (SerialRX_cmd[cmd_recv_index] == 'O') {
				if (SerialRX_cmd[cmd_recv_index_next] == 'M') {	// on screen message
					char msg[16];
					uint8_t msg_i = 0;
					uint8_t msg_len = SerialRX_cmd[cmd_recv_index-2] - 16;
					
					if ((cmd_recv_index-2) > 15) {
						for (uint8_t i = cmd_recv_index-17; i < cmd_recv_index-2; i++) {
							msg[msg_i++] = SerialRX_cmd[i];
						}
					}
					
					LCDsetCursorPosition(2, 0);
					LCDputs(msg);
				}
			} else if (SerialRX_cmd[cmd_recv_index] == 'S') {
				if (SerialRX_cmd[cmd_recv_index_next] == 'T') {	// status
					send_status();
				}
			}
			
			cmd_recv = 0;
		}

//		if (step_fault_changed) {
//			if (step_fault == DRV8884_NO_FAULT) {
//				LCDsetCursorPosition(2, 0);
//				LCDprintf("Stepper: Normal ");
//			} else {
//				LCDsetCursorPosition(2, 0);
//				LCDprintf("Stepper: FAULT! ");
//			}	
//			step_fault_changed = 0;
//		}
		
		if (dc_fault_changed) {
			if (dc_fault == DRV8814_NO_FAULT) {
				LCDsetCursorPosition(1, 0);
				LCDprintf("DC: Normal ");
			} else {
				LCDsetCursorPosition(1, 0);
				LCDprintf("DC: FAULT! ");
			}	
			dc_fault_changed = 0;
		}
	}
}

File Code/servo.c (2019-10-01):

#include "servo.h"

void Servo_Init(uint16_t freq, uint16_t degree) {
	RCC->AHBENR |= RCC_AHBENR_GPIOAEN;		// enable PORT A clocks
	
	RCC->APB1ENR |= RCC_APB1ENR_TIM2EN;		// enable TIM2 clocks
	
	GPIO_PIN_MODE(SERVOPORT,SERVOPIN,AF);					// set PE8 as AF
	
	GPIO_PIN_AF_MODE(SERVOPORT,SERVOPIN,0x01);				// set AF mode
	
	GPIO_PIN_DRV_TYPE(SERVOPORT,SERVOPIN,PP);
	
	CLR_BITS(TIM2->CR1, 0x10);					// clear DIR bit (up-counting)
	
	TIM2->PSC = 719;	// 100KHz counter frequency
	
	TIM2->ARR = freq;	// servo signal frequency
	
	FORCE_BITS(TIM2->CCMR1,0x00F0,0x60);	// PWM mode 1
	
	SET_BITS(TIM2->CR1,0x80);			// auto-reload preload value
	
	FORCE_BITS(TIM2->CCER,(TIM_CCER_CC1NP | TIM_CCER_CC1P | TIM_CCER_CC1E),(TIM_CCER_CC1NP | TIM_CCER_CC1P | TIM_CCER_CC1E));	// complementary output, polarity bit, compare enable 

	int duty = Servo_UsToVal(Servo_degreeToUs(degree));
	TIM2->CCR1 = duty;	// Set duty cycle
	
	SET_BITS(TIM2->CR1,0x01);					// enable counter
}

void Servo_set(uint16_t degree) {
	int val = Servo_UsToVal(Servo_degreeToUs(degree));
	if (val != 0) {
		TIM2->CCR1 = val;	// Set duty cycle
	}
}

void Servo_set_us(uint16_t us_set) {
	int val = Servo_UsToVal(us_set);
	if (val != 0) {
		TIM2->CCR1 = val;	// Set duty cycle
	}
}

void Servo_enable() {
	SET_BITS(TIM2->BDTR,0x8000);			// Enable master output
}

void Servo_disable() {
	CLR_BITS(TIM2->BDTR,0x8000);			// disable master output
}

uint16_t Servo_degreeToUs(uint16_t degree) {
	
	return ((degree*10)+600);
}

uint16_t Servo_UsToVal(uint16_t us) {
	
	uint16_t val = SERVOFREQ-((us*SERVOFREQ)/20100);
	
	if ((val >= SERVOMAX) && (val <= SERVOMIN)) {
		return val;
	} else {
		return 0;
	}
}

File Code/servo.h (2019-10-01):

#ifndef __SERVO_H
#define __SERVO_H

#include "stm32f303xe.h"
#include "utils.h"

#define SERVOPORT		A
#define SERVOPIN		15

// servo signal frequency
#define SERVOFREQ		1999	// 50Hz

// max and min servo values
#define SERVOMAX	 	1750
#define SERVOMIN 		1940

#define SERVOMAXDEG	2300 // 170
#define SERVOMINDEG 1150 // 55

// centre position
#define SERVO_FWD_DEG 		60

void Servo_Init(uint16_t freq, uint16_t duty);
void Servo_set(uint16_t duty);
void Servo_set_us(uint16_t us_set);
void Servo_enable(void);
void Servo_disable(void);
uint16_t Servo_degreeToUs(uint16_t degree);
uint16_t Servo_UsToVal(uint16_t us);

#endif /* __SERVO_H */

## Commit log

2019-01-30 Nucleo Model
    [microcontroller.SchDoc]
2019-01-31 Top Sheet
    [EmbeddedControlSystem_Hengeveld4331.PrjPcb, Top sheet.SchDoc, servo.SchDoc]
2019-01-31 more docs
    [EmbeddedControlSystem_Hengeveld4331.PrjPcb]
2019-02-03 LCD step
    [LCD_NHD-0216K1Z-NSB-FBW-L v19.step]
2019-02-03 LCD Module 3D Model
    [EmbeddedControlSystem_Hengeveld4331.PrjPcb, LCD.SchDoc, Stepper Motor Driver.SchDoc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]
2019-02-03 VBAT BU2032
    [BU2032.step, EmbeddedControlSystem_Hengeveld4331.PrjPcb, microcontroller.SchDoc]
2019-02-05 Power & Func Reqs
    [BU2032.step, LCD.SchDoc, LCD_NHD-0216K1Z-NSB-FBW-L v19.step]
2019-02-06 IO Expansioin
    [IO Expansioin.SchDoc, Top sheet.SchDoc, microcontroller.SchDoc]
2019-02-06 Temp & SD
    [DC Motor Driver.SchDoc, EmbeddedControlSystem_Hengeveld4331.PrjPcb, IO Expansioin.SchDoc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]
2019-02-08 Fixed Errors
    [CANbus.SchDoc, DC Motor Driver.SchDoc, EmbeddedControlSystem_Hengeveld4331.PrjPcb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]
2019-02-08 FINAL SCHEMATICS
    [CANbus.SchDoc, DC Motor Driver.SchDoc, EmbeddedControlSystem_Hengeveld4331.PrjPcb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]
2019-02-10 PCB start
    [Bluetooth.SchDoc, DC Motor Driver.SchDoc, EmbeddedControlSystem_Hengeveld4331.PrjPcb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]
2019-02-10 More PCB
    [Bluetooth.SchDoc, CANbus.SchDoc, DC Motor Driver.SchDoc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]
2019-02-11 PCB Part Placement
    [Bluetooth.SchDoc, CANbus.SchDoc, DC Motor Driver.SchDoc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]
2019-02-12 PCB rules and plane
    [IO Expansioin.SchDoc, SD card.SchDoc, power supply.SchDoc]
2019-02-12 PCB Start Traces
    [EmbeddedControlSystem_Hengeveld4331.PrjPcb, IO Expansioin.SchDoc, TestPoints.SchDoc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]
2019-02-12 Lotsa Traces
    [IO Expansioin.SchDoc, TestPoints.SchDoc, Top sheet.SchDoc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]
2019-02-14 Almost Done
    [CANbus.SchDoc, DC Motor Driver.SchDoc, EmbeddedControlSystem_Hengeveld4331.PrjPcb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]
2019-02-14 DONE routing
    [Bluetooth.SchDoc, DC Motor Driver.SchDoc, EmbeddedControlSystem_Hengeveld4331.PrjPcb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]
2019-02-17 cam files
    [EmbeddedControlSystem_Hengeveld4331.DRL, EmbeddedControlSystem_Hengeveld4331.GBL, EmbeddedControlSystem_Hengeveld4331.GBO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]
2019-02-17 Output Files
    [EmbeddedControlSystem_Hengeveld4331 BoM.xls, EmbeddedControlSystem_Hengeveld4331 BoM.xlsx, EmbeddedControlSystem_Hengeveld4331.PrjPcb]
2019-02-18 PCB Update
    [EmbeddedControlSystem_Hengeveld4331.DRL, EmbeddedControlSystem_Hengeveld4331.GBL, EmbeddedControlSystem_Hengeveld4331.GBO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]
2019-02-19 Latest Output
    [EmbeddedControlSystem_Hengeveld4331.GBL]
2019-02-19 More PCB Fixes
    [Bluetooth.SchDoc, CANbus.SchDoc, Camera Module.SchDoc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]
2019-02-20 New output
    [SD card.SchDoc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]
2019-03-02 DFM Good
    [CANbus.SchDoc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]
2019-03-21 schematic updates rev 2
    [Bluetooth.SchDoc, Camera Module.SchDoc, EmbeddedControlSystem_Hengeveld4331.PrjPcb]
2019-03-21 schematic value updates
    [CANbus.SchDoc, Camera Module.SchDoc, DC Motor Driver.SchDoc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]
2019-03-22 PCB Changes
    [Bluetooth.SchDoc, CANbus.SchDoc, Camera Module.SchDoc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]
2019-03-22 PCB layout update
2019-03-28 Gerber Outputs
    [controller.GBL, controller.GBO, controller.GBP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]
2019-03-29 Power Budget
2019-03-31 PCB Fixes
    [Bluetooth.SchDoc, Camera Module.SchDoc, DC Motor Driver.SchDoc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]
2019-04-01 PCB Rev1.2
    [controller.GBL, controller.GBS, controller.GTL]
2019-04-01 pcb fix
2019-04-02 PCB Fix - trimmer
    [Bluetooth.SchDoc, Camera Module.SchDoc, EmbeddedControlSystem_Hengeveld4331.PrjPcb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]
2019-04-04 Rev1.2 PCB
    [controller.GBL, controller.GBO, controller.GTL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]
2019-09-11 Semester 5 Start
    [EmbeddedControlSystem_Hengeveld4331.PrjPcb]
2019-09-23 Homing and more
2019-10-03 tank controls and diff steering(kinda)
